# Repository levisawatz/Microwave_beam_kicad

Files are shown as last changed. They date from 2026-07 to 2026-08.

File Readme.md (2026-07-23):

# Steerable Microwave Beam Phased Array
Designer: Levi Sawatzky  
Overview Document: https://levisawatz.github.io/assets/microwave_beam/Project_summary.pdf  
Status: In production

## Project Overview 
This project explores the design and construction of a steerable microwave phased array capable of delivering a tightly focused beam of microwave energy toward a target. The system serves as a science demonstration platform that reveals the power and elegance of microwave circuit design, phased arrays, and high-frequency PCB engineering. The core concept is to electronically steer a beam of RF energy without any moving mechanical parts, using phase control across an array of patch antennas. This beam can then be used to transfer wireless power across a distance, light up LEDs, heat up food like a microwave, or boost WIFI 

This PCB was created using Kicad 10

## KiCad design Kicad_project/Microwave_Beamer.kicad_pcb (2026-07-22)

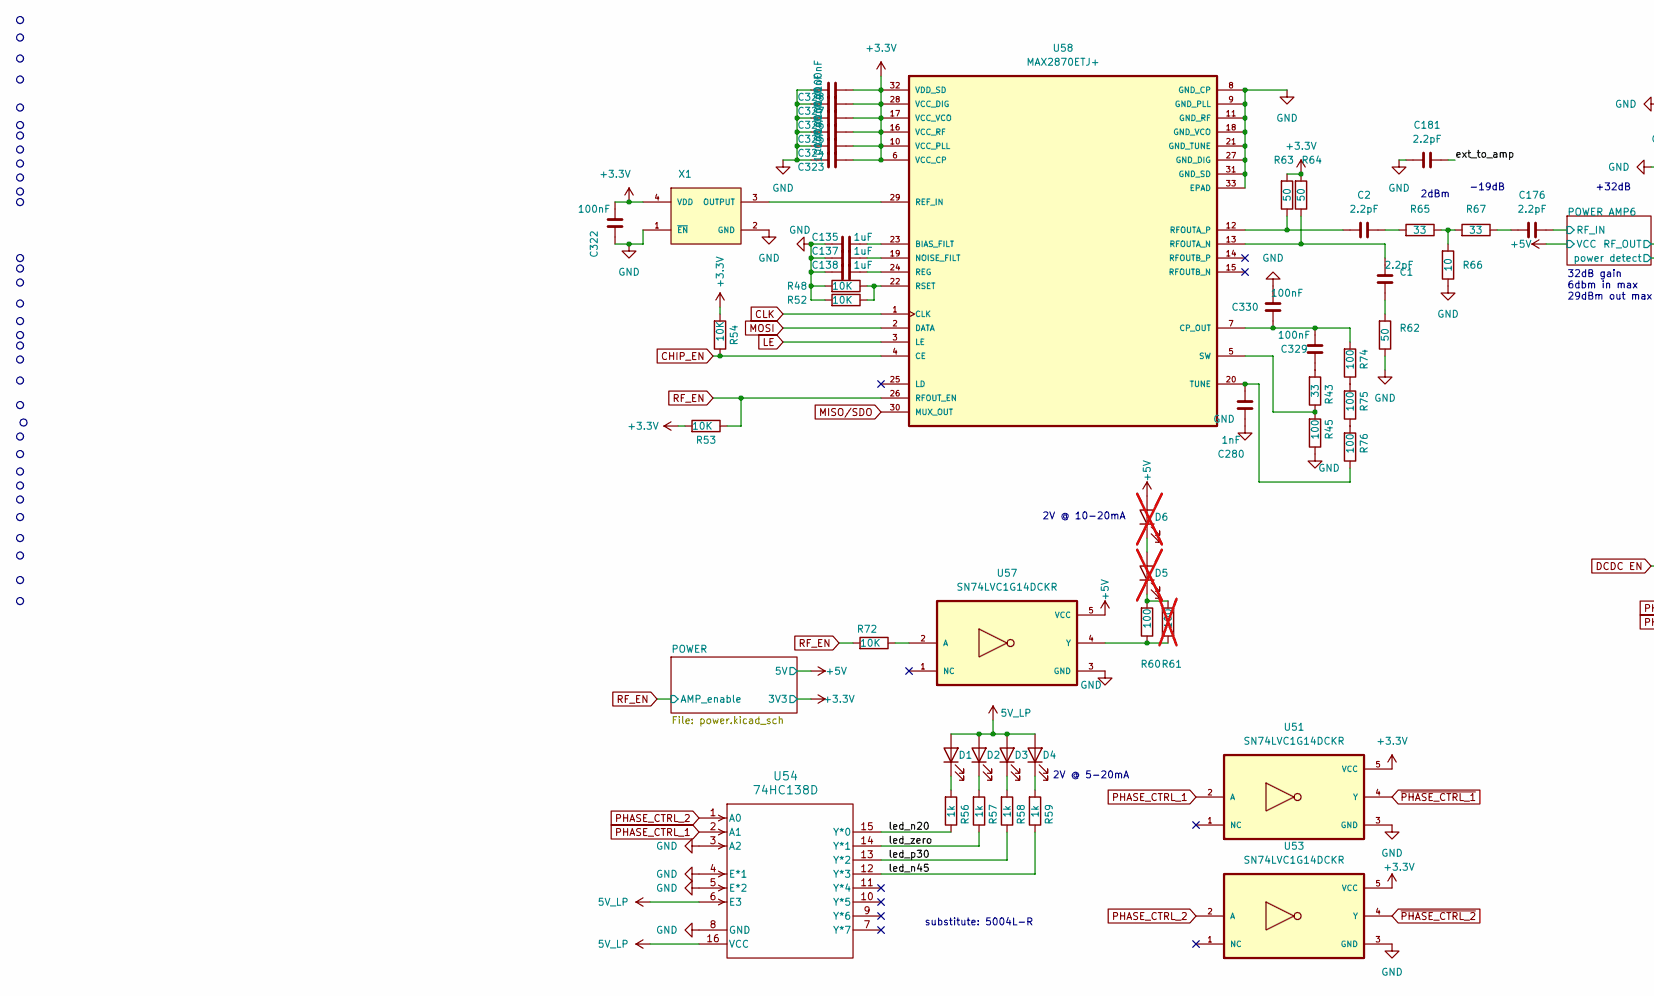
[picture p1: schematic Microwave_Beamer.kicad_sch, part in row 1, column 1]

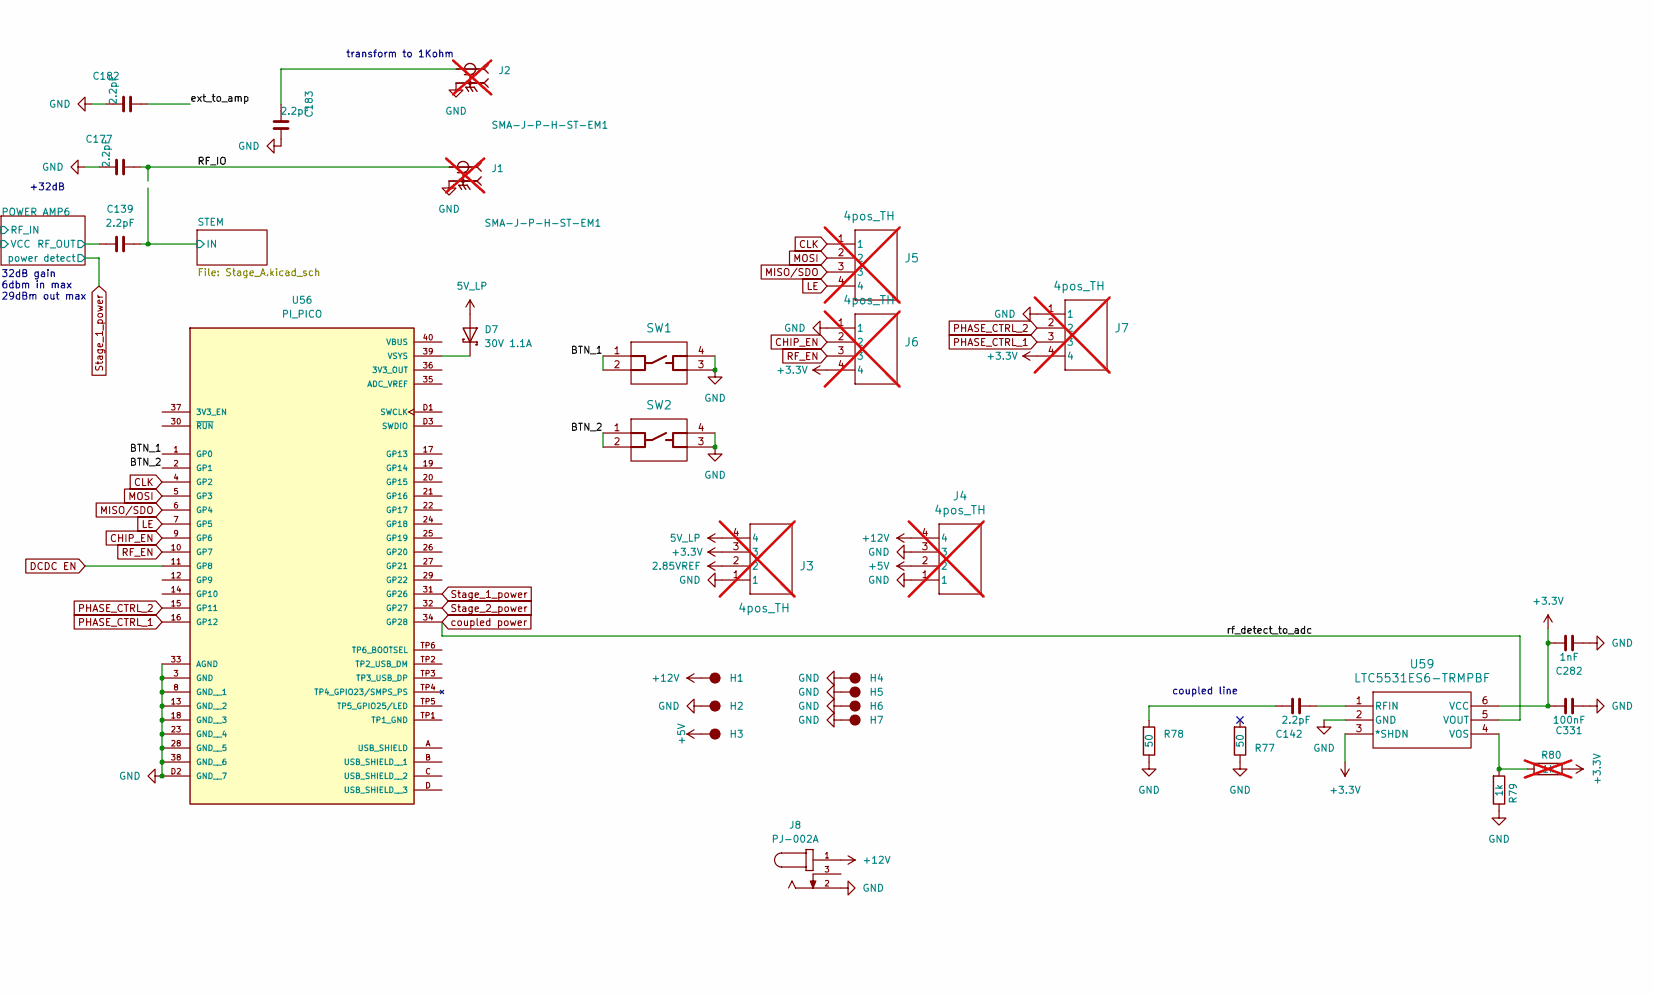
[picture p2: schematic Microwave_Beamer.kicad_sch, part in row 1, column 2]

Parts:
C1, C2, C176: 2.2pF; C_0402_1005Metric; MPN GJM1555C1H2R2WB01D
C135, C137, C138: 1uF; C_0603_1608Metric; MPN GRT188R61H105KE13D
C139, C142, C177, C181, C182, C183: 2.2pF; C_0402_1005Metric_Pad0.74x0.62mm_HandSolder; MPN GJM1555C1H2R2WB01D
C280, C282: 1nF; C_0402_1005Metric; MPN GCM1555C1H102GA16J
C322, C323, C324, C325, C326, C327, C328, C329, C330, C331: 100nF; C_0402_1005Metric; MPN GCM155R71H104KE02J
D1, D2, D3, D4: LTST-C230KGKT; LED_1206_3216Metric; MPN LTST-C230KGKT
D5, D6: LTST-C230KGKT; LED_1206_3216Metric; MPN LTST-C230KRKT; not fitted
D7: 30V 1.1A; CR_03-GS08_VIS; MPN SL03-GS08
H1, H2, H3, H4, H5, H6, H7: Hole; PTH_5mm; MPN DNP
J1, J2: SMA-J-P-H-ST-EM1; SAMTEC_SMA-J-P-H-ST-EM1; PARTREV G; not fitted
J3, J4, J5, J6, J7: 4pos_TH; 4POS-2_54-generic; MPN DNP; not fitted
J8: PJ-002A; CUI_PJ-002A; MPN PJ-002A
R43, R65, R67: 33; R_0402_1005Metric; MPN TNPW040233R0DEED
R45, R60, R74, R75, R76: 100; R_0402_1005Metric; MPN ERA-2AED101X
R48, R52, R53, R54, R72: 10K; R_0603_1608Metric; MPN ERA-3AEB103V
R56, R57, R58, R59, R79: 1k; R_0603_1608Metric; MPN ERA-3AEB102V
R61: 100; R_0402_1005Metric; MPN ERA-2AED101X; not fitted
R62, R63, R64: 50; R_0402_1005Metric; MPN TNPW040249R9BEED
R66: 10; R_0402_1005Metric; MPN TNPW040210R0DEED
R77, R78: 50; R_0402_1005Metric_Pad0.72x0.64mm_HandSolder; MPN TNPW040249R9BEED
R80: 1k; R_0603_1608Metric; MPN ERA-3AEB102V; not fitted
SW1, SW2: PTS526SM15SMTR2 LFS; SON4_PTS526 SM15 SMTR2 LFS_CNK-M; MPN PTS526SM15SMTR2 LFS
U51, U53, U57: SN74LVC1G14DCKR; SOT65P210X110-5N; MPN SN74LVC1G14DCKR
U54: 74HC138D; SOT109-1_NXP; MPN MC74HC138ADR2G
U56: PI_PICO; PI_PICO_SMD; MPN SC0917
U58: MAX2870ETJ+; vco_QFN50P500X500X80-33N; MPN MAX2870ETJ+
U59: LTC5531ES6-TRMPBF; SOT-6_S_LIT-M; MPN LTC5531ES6#TRMPBF
X1: ECS-3225MVQ-1000-CN-TR; OSC_ECS-3225MVQ-1000-CN-TR; MPN ECS-3225MVQ-1000-CN-TR

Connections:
2.85VREF: J3.2; also elsewhere on the board
5V_LP: D1.2 (A), D2.2 (A), D3.2 (A), D4.2 (A), D7.A, J3.4, U54.6 (E3), U54.16 (VCC); also elsewhere on the board
+3.3V: C282.1, C322.2, C323.2, C324.2, C325.2, C326.2, C327.2, C328.2, C331.1, J3.3, J6.4, J7.4, R53.1, R54.1, R63.1, R64.1, R80.2, U51.5 (VCC), U53.5 (VCC), U58.6 (VCC_CP), U58.10 (VCC_PLL), U58.16 (VCC_RF), U58.17 (VCC_VCO), U58.28 (VCC_DIG), U58.32 (VDD_SD), U59.3 (*SHDN), U59.6 (VCC), X1.4 (VDD); also elsewhere on the board
+5V: D6.2 (A), H3.1, J4.2, U57.5 (VCC); also elsewhere on the board
+12V: H1.1, J4.4, J8.1; also elsewhere on the board
/BTN_1: SW1.1, SW1.2, U56.1 (GP0)
/BTN_2: SW2.1, SW2.2, U56.2 (GP1)
/POWER AMP6/RF_IN: C176.2; also elsewhere on the board
/POWER AMP6/RF_OUT: C139.1; also elsewhere on the board
/RF_IO: C177.2, J1.1
/STEM/IN: C139.2; also elsewhere on the board
/ext_to_amp: C181.2, C182.2
/led_n20: R56.2, U54.15 (Y*0)
/led_n45: R59.2, U54.12 (Y*3)
/led_p30: R58.2, U54.13 (Y*2)
/led_zero: R57.2, U54.14 (Y*1)
CHIP_EN: J6.2, R54.2, U56.9 (GP6), U58.4 (CE)
CLK: J5.1, U56.4 (GP2), U58.1 (CLK)
DCDC EN: U56.11 (GP8); also elsewhere on the board
GND: C135.1, C137.1, C138.1, C177.1, C181.1, C182.1, C183.2, C280.2, C282.2, C322.1, C323.1, C324.1, C325.1, C326.1, C327.1, C328.1, C330.1, C331.2, H2.1, H4.1, H5.1, H6.1, H7.1, J1.2_1, J1.2_2, J1.3_1, J1.3_2, J2.2_1, J2.2_2, J2.3_1, J2.3_2, J3.1, J4.1, J4.3, J6.1, J7.1, J8.2, R45.2, R48.1, R52.1, R62.2, R66.2, R77.2, R78.2, R79.2, SW1.3, SW1.4, SW2.3, SW2.4, U51.3 (GND), U53.3 (GND), U54.3 (A2), U54.4 (E*1), U54.5 (E*2), U54.8 (GND), U56.3 (GND), U56.8 (GND__1), U56.13 (GND__2), U56.18 (GND__3), U56.23 (GND__4), U56.28 (GND__5), U56.33 (AGND), U56.38 (GND__6), U56.D2 (GND__7), U57.3 (GND), U58.8 (GND_CP), U58.9 (GND_PLL), U58.11 (GND_RF), U58.18 (GND_VCO), U58.21 (GND_TUNE), U58.27 (GND_DIG), U58.31 (GND_SD), U58.33 (EPAD), U59.2 (GND), X1.1 (~EN), X1.2 (GND); also elsewhere on the board
LE: J5.4, U56.7 (GP5), U58.3 (LE)
MISO/SDO: J5.3, U56.6 (GP4), U58.30 (MUX_OUT)
MOSI: J5.2, U56.5 (GP3), U58.2 (DATA)
unnamed: C1.2, R62.1
unnamed: C2.2, R65.1
unnamed: C142.1, R78.1
unnamed: C176.1, R67.2
unnamed: C183.1, J2.1
unnamed: C329.2, R43.1
unnamed: D1.1 (K), R56.1
unnamed: D2.1 (K), R57.1
unnamed: D3.1 (K), R58.1
unnamed: D4.1 (K), R59.1
unnamed: D5.2 (A), D6.1 (K)
unnamed: D5.1 (K), R60.1, R61.1
unnamed: R65.2, R66.1, R67.1
unnamed: R74.2, R75.1
unnamed: R75.2, R76.1
unnamed: D7.K, U56.39 (VSYS)
unnamed: R72.2, U57.2 (A)
unnamed: R60.2, R61.2, U57.4 (Y)
unnamed: C135.2, U58.23 (BIAS_FILT)
unnamed: C329.1, C330.2, R74.1, U58.7 (CP_OUT)
unnamed: C137.2, U58.19 (NOISE_FILT)
unnamed: U58.29 (REF_IN), X1.3 (OUTPUT)
unnamed: C138.2, U58.24 (REG)
unnamed: C1.1, R64.2, U58.13 (RFOUTA_N)
unnamed: C2.1, R63.2, U58.12 (RFOUTA_P)
unnamed: R48.2, R52.2, U58.22 (RSET)
unnamed: R43.2, R45.1, U58.5 (SW)
unnamed: C280.1, R76.2, U58.20 (TUNE)
unnamed: C142.2, U59.1 (RFIN)
unnamed: R79.1, R80.1, U59.4 (VOS)
PHASE_CTRL_1: J7.3, U51.2 (A), U54.2 (A1), U56.16 (GP12); also elsewhere on the board
PHASE_CTRL_2: J7.2, U53.2 (A), U54.1 (A0), U56.15 (GP11); also elsewhere on the board
RF_EN: J6.3, R53.2, R72.1, U56.10 (GP7), U58.26 (RFOUT_EN); also elsewhere on the board
Stage_1_power: U56.31 (GP26); also elsewhere on the board
Stage_2_power: U56.32 (GP27); also elsewhere on the board
coupled power: U56.34 (GP28), U59.5 (VOUT)
~PHASE_CTRL_1: U51.4 (Y); also elsewhere on the board
~PHASE_CTRL_2: U53.4 (Y); also elsewhere on the board

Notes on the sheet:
coupled line
2V @ 10-20mA
32dB gain 6dbm in max 29dBm out max
2dBm
-19dB
transform to 1Kohm
2V @ 5-20mA
+32dB
substitute: 5004L-R

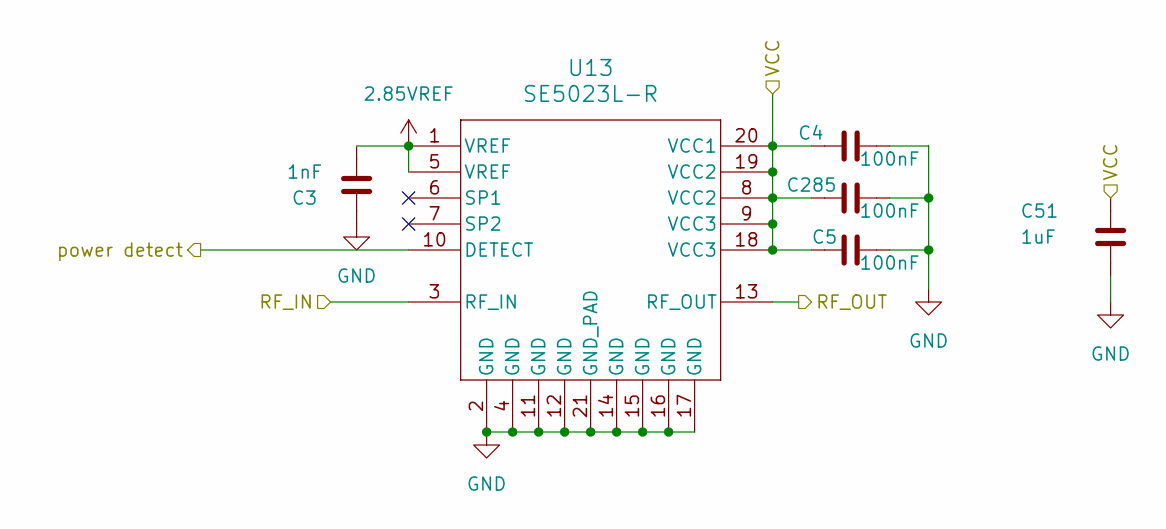
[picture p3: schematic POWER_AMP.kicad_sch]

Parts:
C3: 1nF; C_0402_1005Metric; MPN GCM1555C1H102GA16J
C4, C5, C285: 100nF; C_0402_1005Metric; MPN GCM155R71H104KE02J
C51: 1uF; C_0603_1608Metric; MPN GRT188R61H105KE13D
U13: SE5023L-R; QFN20_4X4_STM; MPN 5004L-R

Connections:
2.85VREF: C3.1, U13.1 (VREF), U13.5 (VREF); also elsewhere on the board
+5V: C4.1, C5.1, C51.1, C285.1, U13.8 (VCC2), U13.9 (VCC3), U13.18 (VCC3), U13.19 (VCC2), U13.20 (VCC1); also elsewhere on the board
/STEM/FAN_A/Antenna_1: U13.13 (RF_OUT)
/STEM/FAN_A/FANFAN A/OUT1: U13.3 (RF_IN); also elsewhere on the board
/STEM/FAN_A/POWER AMP1/power detect: U13.10 (DETECT)
GND: C3.2, C4.2, C5.2, C51.2, C285.2, U13.2 (GND), U13.4 (GND), U13.11 (GND), U13.12 (GND), U13.14 (GND), U13.15 (GND), U13.16 (GND), U13.17 (GND), U13.21 (GND_PAD); also elsewhere on the board

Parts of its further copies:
C6, C7, C8, C9, C25, C26, C27, C28, C29, C30, C39, C40, C41, C42, C43, C44, C46, C47, C48, C49, C50, C61, C75, C89, C103, C117, C131, C145, C159, C173, C187, C201, C215, C229, C243, C257, C286, C287, C288, C289, C290, C291, C292, C293, C294, C295, C296, C297, C298, C299, C300, C301, C302, C303: 100nF; C_0402_1005Metric; MPN GCM155R71H104KE02J
C24, C38, C45, C59, C73, C87, C101, C115, C129, C143, C157, C171, C185, C199, C213, C227, C241, C255: 1nF; C_0402_1005Metric; MPN GCM1555C1H102GA16J
C60, C62, C63, C64, C65, C74, C76, C77, C78, C79, C88, C90, C91, C92, C93, C102, C104, C105: 1uF; C_0603_1608Metric; MPN GRT188R61H105KE13D
U16, U18, U19, U21, U23, U25, U27, U29, U31, U33, U35, U37, U39, U41, U43, U45, U47, U49: SE5023L-R; QFN20_4X4_STM; MPN 5004L-R

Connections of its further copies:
2.85VREF: C24.1, C38.1, C45.1, C59.1, C73.1, C87.1, C101.1, C115.1, C129.1, C143.1, C157.1, C171.1, C185.1, C199.1, C213.1, C227.1, C241.1, C255.1, U16.1 (VREF), U16.5 (VREF), U18.1 (VREF), U18.5 (VREF), U19.1 (VREF), U19.5 (VREF), U21.1 (VREF), U21.5 (VREF), U23.1 (VREF), U23.5 (VREF), U25.1 (VREF), U25.5 (VREF), U27.1 (VREF), U27.5 (VREF), U29.1 (VREF), U29.5 (VREF), U31.1 (VREF), U31.5 (VREF), U33.1 (VREF), U33.5 (VREF), U35.1 (VREF), U35.5 (VREF), U37.1 (VREF), U37.5 (VREF), U39.1 (VREF), U39.5 (VREF), U41.1 (VREF), U41.5 (VREF), U43.1 (VREF), U43.5 (VREF), U45.1 (VREF), U45.5 (VREF), U47.1 (VREF), U47.5 (VREF), U49.1 (VREF), U49.5 (VREF); also elsewhere on the board
+5V: C6.1, C7.1, C8.1, C9.1, C25.1, C26.1, C27.1, C28.1, C29.1, C30.1, C39.1, C40.1, C41.1, C42.1, C43.1, C44.1, C46.1, C47.1, C48.1, C49.1, C50.1, C60.1, C61.1, C62.1, C63.1, C64.1, C65.1, C74.1, C75.1, C76.1, C77.1, C78.1, C79.1, C88.1, C89.1, C90.1, C91.1, C92.1, C93.1, C102.1, C103.1, C104.1, C105.1, C117.1, C131.1, C145.1, C159.1, C173.1, C187.1, C201.1, C215.1, C229.1, C243.1, C257.1, C286.1, C287.1, C288.1, C289.1, C290.1, C291.1, C292.1, C293.1, C294.1, C295.1, C296.1, C297.1, C298.1, C299.1, C300.1, C301.1, C302.1, C303.1, U16.8 (VCC2), U16.9 (VCC3), U16.18 (VCC3), U16.19 (VCC2), U16.20 (VCC1), U18.8 (VCC2), U18.9 (VCC3), U18.18 (VCC3), U18.19 (VCC2), U18.20 (VCC1), U19.8 (VCC2), U19.9 (VCC3), U19.18 (VCC3), U19.19 (VCC2), U19.20 (VCC1), U21.8 (VCC2), U21.9 (VCC3), U21.18 (VCC3), U21.19 (VCC2), U21.20 (VCC1), U23.8 (VCC2), U23.9 (VCC3), U23.18 (VCC3), U23.19 (VCC2), U23.20 (VCC1), U25.8 (VCC2), U25.9 (VCC3), U25.18 (VCC3), U25.19 (VCC2), U25.20 (VCC1), U27.8 (VCC2), U27.9 (VCC3), U27.18 (VCC3), U27.19 (VCC2), U27.20 (VCC1), U29.8 (VCC2), U29.9 (VCC3), U29.18 (VCC3), U29.19 (VCC2), U29.20 (VCC1), U31.8 (VCC2), U31.9 (VCC3), U31.18 (VCC3), U31.19 (VCC2), U31.20 (VCC1), U33.8 (VCC2), U33.9 (VCC3), U33.18 (VCC3), U33.19 (VCC2), U33.20 (VCC1), U35.8 (VCC2), U35.9 (VCC3), U35.18 (VCC3), U35.19 (VCC2), U35.20 (VCC1), U37.8 (VCC2), U37.9 (VCC3), U37.18 (VCC3), U37.19 (VCC2), U37.20 (VCC1), U39.8 (VCC2), U39.9 (VCC3), U39.18 (VCC3), U39.19 (VCC2), U39.20 (VCC1), U41.8 (VCC2), U41.9 (VCC3), U41.18 (VCC3), U41.19 (VCC2), U41.20 (VCC1), U43.8 (VCC2), U43.9 (VCC3), U43.18 (VCC3), U43.19 (VCC2), U43.20 (VCC1), U45.8 (VCC2), U45.9 (VCC3), U45.18 (VCC3), U45.19 (VCC2), U45.20 (VCC1), U47.8 (VCC2), U47.9 (VCC3), U47.18 (VCC3), U47.19 (VCC2), U47.20 (VCC1), U49.8 (VCC2), U49.9 (VCC3), U49.18 (VCC3), U49.19 (VCC2), U49.20 (VCC1); also elsewhere on the board
/POWER AMP6/RF_IN: U49.3 (RF_IN); also elsewhere on the board
/POWER AMP6/RF_OUT: U49.13 (RF_OUT); also elsewhere on the board
/STEM/FAN_A/Antenna_3: U16.13 (RF_OUT)
/STEM/FAN_A/Antenna_5: U18.13 (RF_OUT)
/STEM/FAN_A/FANFAN A/OUT3: U16.3 (RF_IN); also elsewhere on the board
/STEM/FAN_A/FANFAN A/OUT5: U18.3 (RF_IN); also elsewhere on the board
/STEM/FAN_A/POWER AMP3/power detect: U16.10 (DETECT)
/STEM/FAN_A/power_det: U18.10 (DETECT)
/STEM/FAN_B/Antenna_1: U19.13 (RF_OUT)
/STEM/FAN_B/Antenna_3: U21.13 (RF_OUT)
/STEM/FAN_B/Antenna_5: U23.13 (RF_OUT)
/STEM/FAN_B/FANFAN A/OUT1: U19.3 (RF_IN); also elsewhere on the board
/STEM/FAN_B/FANFAN A/OUT3: U21.3 (RF_IN); also elsewhere on the board
/STEM/FAN_B/FANFAN A/OUT5: U23.3 (RF_IN); also elsewhere on the board
/STEM/FAN_B/POWER AMP1/power detect: U19.10 (DETECT)
/STEM/FAN_B/POWER AMP3/power detect: U21.10 (DETECT)
/STEM/FAN_C/Antenna_1: U25.13 (RF_OUT)
/STEM/FAN_C/Antenna_3: U27.13 (RF_OUT)
/STEM/FAN_C/Antenna_5: U29.13 (RF_OUT)
/STEM/FAN_C/FANFAN A/OUT1: U25.3 (RF_IN); also elsewhere on the board
/STEM/FAN_C/FANFAN A/OUT3: U27.3 (RF_IN); also elsewhere on the board
/STEM/FAN_C/FANFAN A/OUT5: U29.3 (RF_IN); also elsewhere on the board
/STEM/FAN_C/POWER AMP1/power detect: U25.10 (DETECT)
/STEM/FAN_C/POWER AMP3/power detect: U27.10 (DETECT)
/STEM/FAN_C/power_det: U29.10 (DETECT)
/STEM/FAN_D/Antenna_1: U31.13 (RF_OUT)
/STEM/FAN_D/Antenna_3: U33.13 (RF_OUT)
/STEM/FAN_D/Antenna_5: U35.13 (RF_OUT)
/STEM/FAN_D/FANFAN A/OUT1: U31.3 (RF_IN); also elsewhere on the board
/STEM/FAN_D/FANFAN A/OUT3: U33.3 (RF_IN); also elsewhere on the board
/STEM/FAN_D/FANFAN A/OUT5: U35.3 (RF_IN); also elsewhere on the board
/STEM/FAN_D/POWER AMP1/power detect: U31.10 (DETECT)
/STEM/FAN_D/POWER AMP3/power detect: U33.10 (DETECT)
/STEM/FAN_D/power_det: U35.10 (DETECT)
/STEM/FAN_E/Antenna_1: U37.13 (RF_OUT)
/STEM/FAN_E/Antenna_3: U39.13 (RF_OUT)
/STEM/FAN_E/Antenna_5: U41.13 (RF_OUT)
/STEM/FAN_E/FANFAN A/OUT1: U37.3 (RF_IN); also elsewhere on the board
/STEM/FAN_E/FANFAN A/OUT3: U39.3 (RF_IN); also elsewhere on the board
/STEM/FAN_E/FANFAN A/OUT5: U41.3 (RF_IN); also elsewhere on the board
/STEM/FAN_E/POWER AMP1/power detect: U37.10 (DETECT)
/STEM/FAN_E/POWER AMP3/power detect: U39.10 (DETECT)
/STEM/FAN_E/power_det: U41.10 (DETECT)
/STEM/FAN_F/Antenna_1: U43.13 (RF_OUT)
/STEM/FAN_F/Antenna_3: U45.13 (RF_OUT)
/STEM/FAN_F/Antenna_5: U47.13 (RF_OUT)
/STEM/FAN_F/FANFAN A/OUT1: U43.3 (RF_IN); also elsewhere on the board
/STEM/FAN_F/FANFAN A/OUT3: U45.3 (RF_IN); also elsewhere on the board
/STEM/FAN_F/FANFAN A/OUT5: U47.3 (RF_IN); also elsewhere on the board
/STEM/FAN_F/POWER AMP1/power detect: U43.10 (DETECT)
/STEM/FAN_F/POWER AMP3/power detect: U45.10 (DETECT)
/STEM/FAN_F/power_det: U47.10 (DETECT)
GND: C6.2, C7.2, C8.2, C9.2, C24.2, C25.2, C26.2, C27.2, C28.2, C29.2, C30.2, C38.2, C39.2, C40.2, C41.2, C42.2, C43.2, C44.2, C45.2, C46.2, C47.2, C48.2, C49.2, C50.2, C59.2, C60.2, C61.2, C62.2, C63.2, C64.2, C65.2, C73.2, C74.2, C75.2, C76.2, C77.2, C78.2, C79.2, C87.2, C88.2, C89.2, C90.2, C91.2, C92.2, C93.2, C101.2, C102.2, C103.2, C104.2, C105.2, C115.2, C117.2, C129.2, C131.2, C143.2, C145.2, C157.2, C159.2, C171.2, C173.2, C185.2, C187.2, C199.2, C201.2, C213.2, C215.2, C227.2, C229.2, C241.2, C243.2, C255.2, C257.2, C286.2, C287.2, C288.2, C289.2, C290.2, C291.2, C292.2, C293.2, C294.2, C295.2, C296.2, C297.2, C298.2, C299.2, C300.2, C301.2, C302.2, C303.2, U16.2 (GND), U16.4 (GND), U16.11 (GND), U16.12 (GND), U16.14 (GND), U16.15 (GND), U16.16 (GND), U16.17 (GND), U16.21 (GND_PAD), U18.2 (GND), U18.4 (GND), U18.11 (GND), U18.12 (GND), U18.14 (GND), U18.15 (GND), U18.16 (GND), U18.17 (GND), U18.21 (GND_PAD), U19.2 (GND), U19.4 (GND), U19.11 (GND), U19.12 (GND), U19.14 (GND), U19.15 (GND), U19.16 (GND), U19.17 (GND), U19.21 (GND_PAD), U21.2 (GND), U21.4 (GND), U21.11 (GND), U21.12 (GND), U21.14 (GND), U21.15 (GND), U21.16 (GND), U21.17 (GND), U21.21 (GND_PAD), U23.2 (GND), U23.4 (GND), U23.11 (GND), U23.12 (GND), U23.14 (GND), U23.15 (GND), U23.16 (GND), U23.17 (GND), U23.21 (GND_PAD), U25.2 (GND), U25.4 (GND), U25.11 (GND), U25.12 (GND), U25.14 (GND), U25.15 (GND), U25.16 (GND), U25.17 (GND), U25.21 (GND_PAD), U27.2 (GND), U27.4 (GND), U27.11 (GND), U27.12 (GND), U27.14 (GND), U27.15 (GND), U27.16 (GND), U27.17 (GND), U27.21 (GND_PAD), U29.2 (GND), U29.4 (GND), U29.11 (GND), U29.12 (GND), U29.14 (GND), U29.15 (GND), U29.16 (GND), U29.17 (GND), U29.21 (GND_PAD), U31.2 (GND), U31.4 (GND), U31.11 (GND), U31.12 (GND), U31.14 (GND), U31.15 (GND), U31.16 (GND), U31.17 (GND), U31.21 (GND_PAD), U33.2 (GND), U33.4 (GND), U33.11 (GND), U33.12 (GND), U33.14 (GND), U33.15 (GND), U33.16 (GND), U33.17 (GND), U33.21 (GND_PAD), U35.2 (GND), U35.4 (GND), U35.11 (GND), U35.12 (GND), U35.14 (GND), U35.15 (GND), U35.16 (GND), U35.17 (GND), U35.21 (GND_PAD), U37.2 (GND), U37.4 (GND), U37.11 (GND), U37.12 (GND), U37.14 (GND), U37.15 (GND), U37.16 (GND), U37.17 (GND), U37.21 (GND_PAD), U39.2 (GND), U39.4 (GND), U39.11 (GND), U39.12 (GND), U39.14 (GND), U39.15 (GND), U39.16 (GND), U39.17 (GND), U39.21 (GND_PAD), U41.2 (GND), U41.4 (GND), U41.11 (GND), U41.12 (GND), U41.14 (GND), U41.15 (GND), U41.16 (GND), U41.17 (GND), U41.21 (GND_PAD), U43.2 (GND), U43.4 (GND), U43.11 (GND), U43.12 (GND), U43.14 (GND), U43.15 (GND), U43.16 (GND), U43.17 (GND), U43.21 (GND_PAD), U45.2 (GND), U45.4 (GND), U45.11 (GND), U45.12 (GND), U45.14 (GND), U45.15 (GND), U45.16 (GND), U45.17 (GND), U45.21 (GND_PAD), U47.2 (GND), U47.4 (GND), U47.11 (GND), U47.12 (GND), U47.14 (GND), U47.15 (GND), U47.16 (GND), U47.17 (GND), U47.21 (GND_PAD), U49.2 (GND), U49.4 (GND), U49.11 (GND), U49.12 (GND), U49.14 (GND), U49.15 (GND), U49.16 (GND), U49.17 (GND), U49.21 (GND_PAD); also elsewhere on the board
Stage_1_power: U49.10 (DETECT); also elsewhere on the board
Stage_2_power: U23.10 (DETECT); also elsewhere on the board

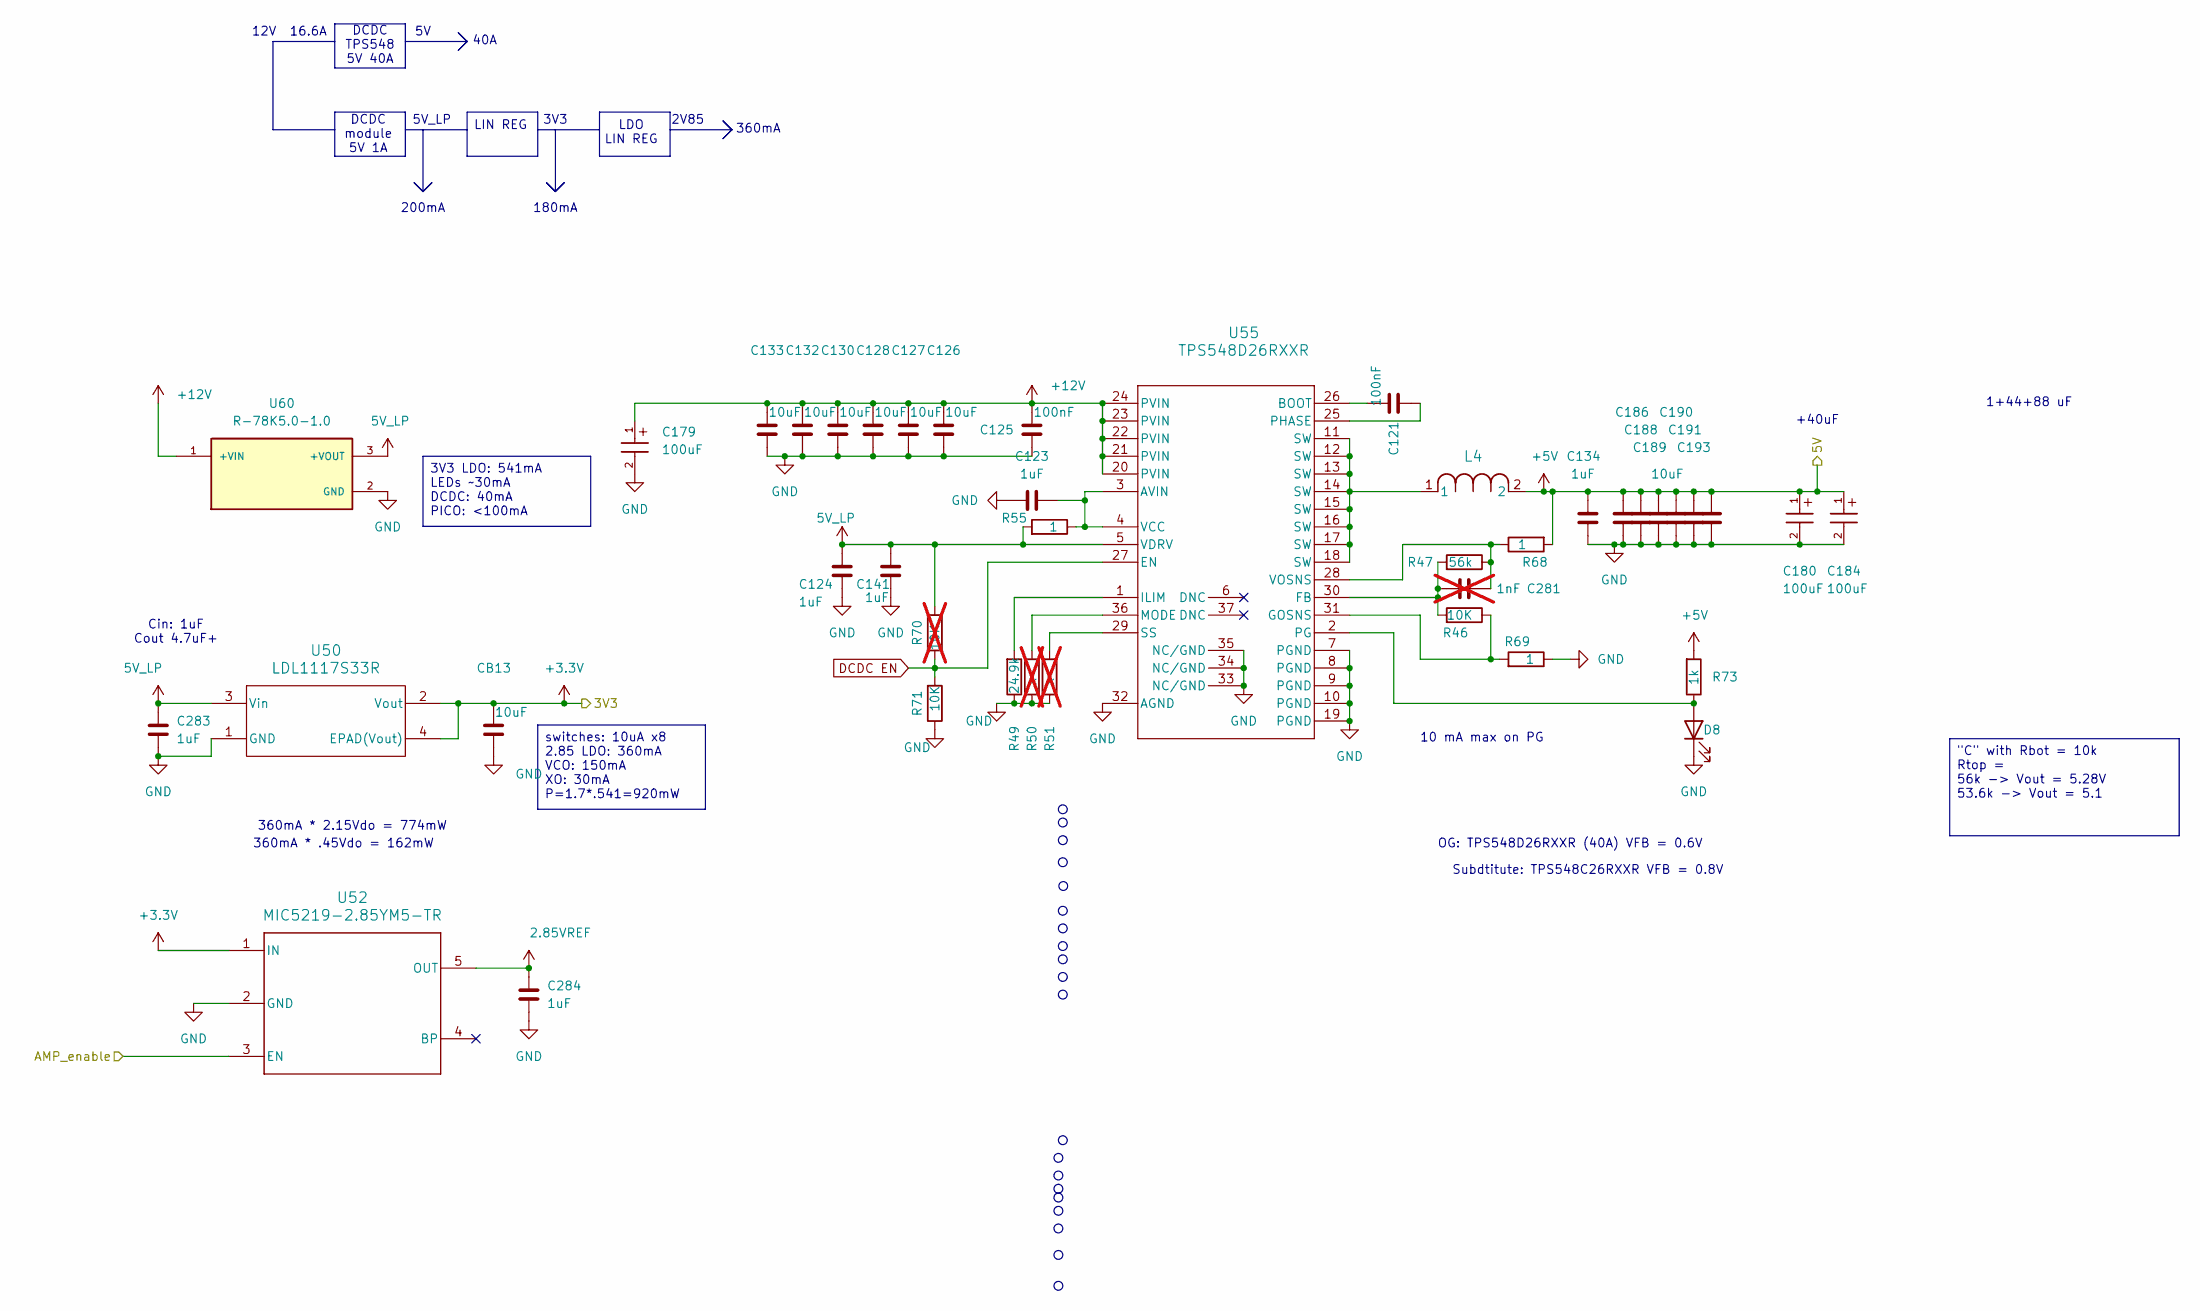
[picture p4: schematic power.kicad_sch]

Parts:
C121, C125: 100nF; C_0402_1005Metric; MPN GCM155R71H104KE02J
C123, C124, C134, C141, C283, C284: 1uF; C_0603_1608Metric; MPN GRT188R61H105KE13D
C126, C127, C128, C130, C132, C133, C186, C188, C189, C190, C191, C193: 10uF; C_1206_3216Metric; MPN GRT31CR6YA106KE01K
C179, C180, C184: 100uF; WCAP-ASLI_6.3X7.7_DXL_; MPN 865080545012
C281: 1nF; C_0402_1005Metric; MPN GCM1555C1H102GA16J; not fitted
CB13: 10uF; C_1206_3216Metric; MPN GRT31CR6YA106KE01K
D8: LTST-C230KGKT; LED_1206_3216Metric; MPN LTST-C230KGKT
L4: IHLP6767GZERR47M11; IND_IHLP-6767GZ_VIS; MPN IHLP6767GZERR47M11
R46, R71: 10K; R_0603_1608Metric; MPN ERA-3AEB103V
R47: 56k; R_0603_1608Metric; MPN ERA-3AEB563V
R49: 24.9k; R_0603_1608Metric; MPN ERA-3AEB2492V
R50, R51: x; R_0603_1608Metric; MPN x; not fitted
R55, R68, R69: 1; R_0603_1608Metric; MPN ERJ-3RQF1R0V
R70: 10K; R_0603_1608Metric; MPN ERA-3AEB103V; not fitted
R73: 1k; R_0603_1608Metric; MPN ERA-3AEB102V
U50: LDL1117S33R; SOT-223_DIO; MPN LDL1117S33R (LDI1117-3.3H)
U52: MIC5219-2.85YM5-TR; SOT23-5; MPN MIC5219-2.85YM5-TR
U55: TPS548D26RXXR; WQFN_C26RXXR_TEX; MPN TPS548D26RXXR
U60: R-78K5.0-1.0; DCDC_R-78K3.3-0.5; MPN R-78K5.0-1.0

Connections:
2.85VREF: C284.1, U52.5 (OUT); also elsewhere on the board
5V_LP: C124.1, C141.1, C283.1, R55.1, R70.2, U50.3 (Vin), U55.5 (VDRV), U60.3 (+VOUT); also elsewhere on the board
+3.3V: CB13.1, U50.2 (Vout), U50.4 (EPAD(Vout)), U52.1 (IN); also elsewhere on the board
+5V: C134.1, C180.1, C184.1, C186.1, C188.1, C189.1, C190.1, C191.1, C193.1, L4.2, R68.1, R73.1; also elsewhere on the board
+12V: C125.1, C126.1, C127.1, C128.1, C130.1, C132.1, C133.1, C179.1, U55.20 (PVIN), U55.21 (PVIN), U55.22 (PVIN), U55.23 (PVIN), U55.24 (PVIN), U60.1 (+VIN); also elsewhere on the board
DCDC EN: R70.1, R71.1, U55.27 (EN); also elsewhere on the board
GND: C123.2, C124.2, C125.2, C126.2, C127.2, C128.2, C130.2, C132.2, C133.2, C134.2, C141.2, C179.2, C180.2, C184.2, C186.2, C188.2, C189.2, C190.2, C191.2, C193.2, C283.2, C284.2, CB13.2, D8.1 (K), R49.2, R50.2, R51.2, R69.2, R71.2, U50.1 (GND), U52.2 (GND), U55.7 (PGND), U55.8 (PGND), U55.9 (PGND), U55.10 (PGND), U55.19 (PGND), U55.32 (AGND), U55.33 (NC/GND), U55.34 (NC/GND), U55.35 (NC/GND), U60.2 (GND); also elsewhere on the board
unnamed: D8.2 (A), R73.2, U55.2 (PG)
unnamed: L4.1, U55.11 (SW), U55.12 (SW), U55.13 (SW), U55.14 (SW), U55.15 (SW), U55.16 (SW), U55.17 (SW), U55.18 (SW)
unnamed: C123.1, R55.2, U55.3 (AVIN), U55.4 (VCC)
unnamed: C121.1, U55.26 (BOOT)
unnamed: C281.1, R46.1, R47.1, U55.30 (FB)
unnamed: R46.2, R69.1, U55.31 (GOSNS)
unnamed: R49.1, U55.1 (ILIM)
unnamed: R50.1, U55.36 (MODE)
unnamed: C121.2, U55.25 (PHASE)
unnamed: R51.1, U55.29 (SS)
unnamed: C281.2, R47.2, R68.2, U55.28 (VOSNS)
RF_EN: U52.3 (EN); also elsewhere on the board

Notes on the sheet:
360mA * .45Vdo = 162mW
2V85
LIN REG
180mA
360mA * 2.15Vdo = 774mW
5V_LP
16.6A
1+44+88 uF
360mA
200mA
Subdtitute: TPS548C26RXXR VFB = 0.8V
OG: TPS548D26RXXR (40A) VFB = 0.6V
DCDC module 5V 1A
Cin: 1uF Cout 4.7uF+
3V3
LDO LIN REG
10 mA max on PG
+40uF
40A
DCDC TPS548 5V 40A
12V
switches: 10uA x8 2.85 LDO: 360mA VCO: 150mA XO: 30mA P=1.7*.541=920mW
"C" with Rbot = 10k Rtop = 56k -> Vout = 5.28V 53.6k -> Vout = 5.1
3V3 LDO: 541mA LEDs ~30mA DCDC: 40mA PICO: <100mA

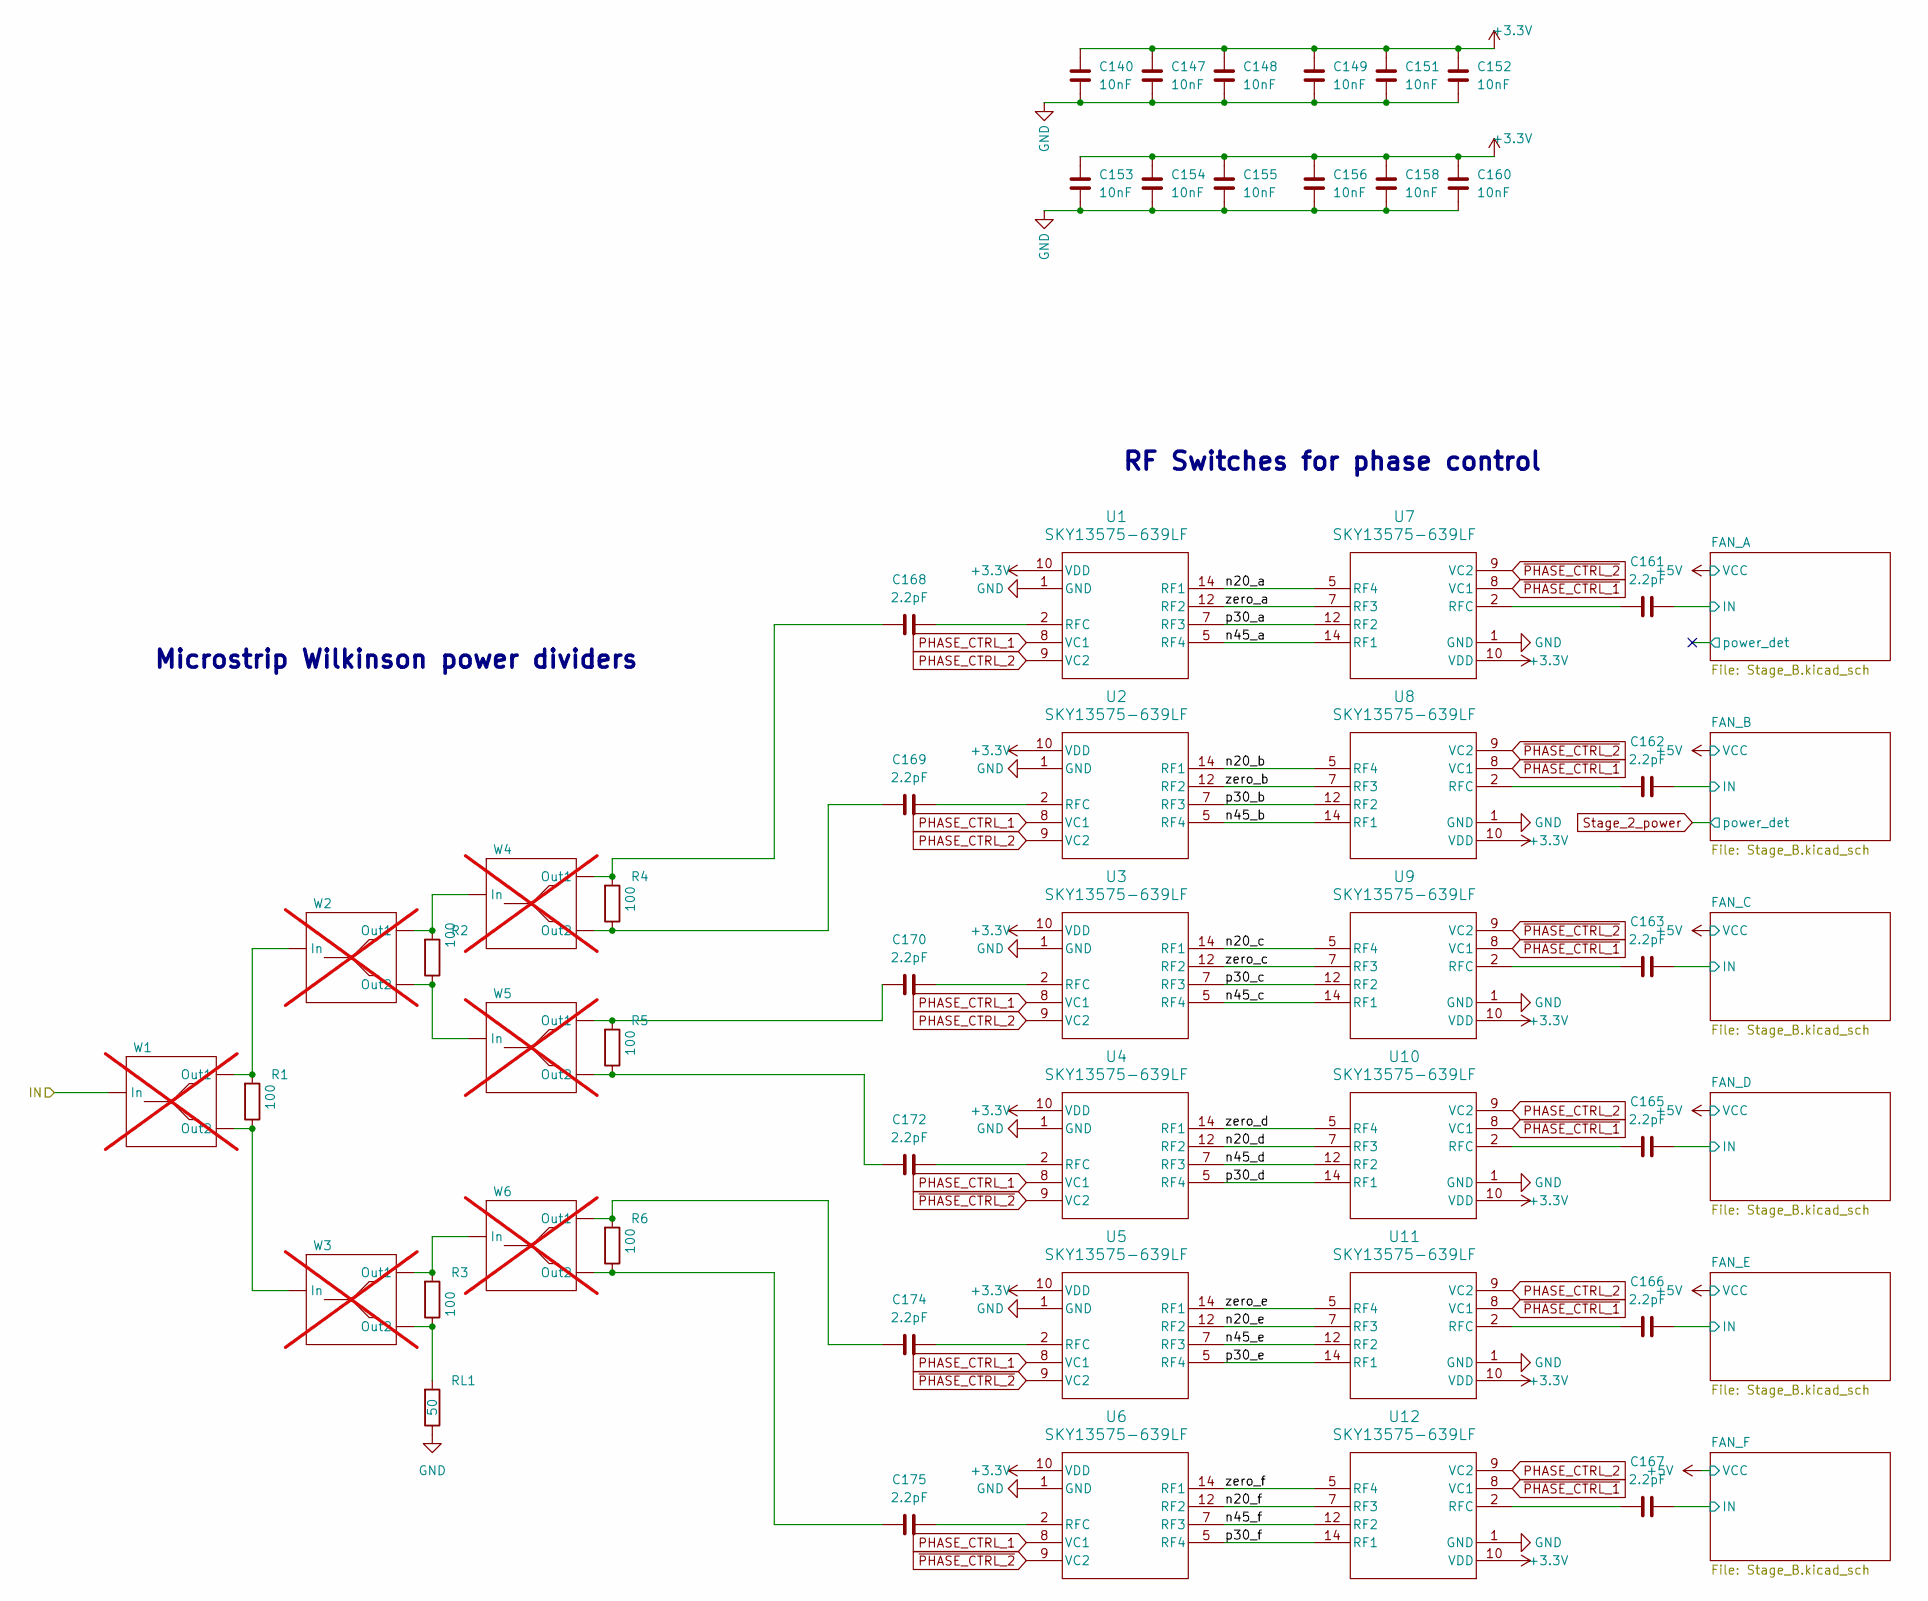
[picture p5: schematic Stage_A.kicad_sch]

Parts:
C140, C147, C148, C149, C151, C152, C153, C154, C155, C156, C158, C160: 10nF; C_0402_1005Metric; MPN GCM155R71H103KA55D
C161, C162, C163, C165, C166, C167, C168, C169, C170, C172, C174, C175: 2.2pF; C_0402_1005Metric; MPN GJM1555C1H2R2WB01D
R1, R2, R3, R4, R5, R6: 100; R_0402_1005Metric; MPN ERA-2AED101X
RL1: 50; R_0402_1005Metric; MPN TNPW040249R9BEED
U1, U2, U3, U4, U5, U6, U7, U8, U9, U10, U11, U12: SKY13575-639LF; SW_SKY13575-639LF; MPN SKY13575-639LF
W1, W2, W3, W4, W5, W6: splitter; 50-70.7 Y; not fitted

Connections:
+3.3V: C140.1, C147.1, C148.1, C149.1, C151.1, C152.1, C153.1, C154.1, C155.1, C156.1, C158.1, C160.1, U1.10 (VDD), U2.10 (VDD), U3.10 (VDD), U4.10 (VDD), U5.10 (VDD), U6.10 (VDD), U7.10 (VDD), U8.10 (VDD), U9.10 (VDD), U10.10 (VDD), U11.10 (VDD), U12.10 (VDD); also elsewhere on the board
/STEM/FAN_A/IN: C161.2; also elsewhere on the board
/STEM/FAN_B/IN: C162.2; also elsewhere on the board
/STEM/FAN_C/IN: C163.2; also elsewhere on the board
/STEM/FAN_D/IN: C165.2; also elsewhere on the board
/STEM/FAN_E/IN: C166.2; also elsewhere on the board
/STEM/FAN_F/IN: C167.2; also elsewhere on the board
/STEM/IN: W1.1 (In); also elsewhere on the board
/STEM/n20_a: U1.14 (RF1), U7.5 (RF4)
/STEM/n20_b: U2.14 (RF1), U8.5 (RF4)
/STEM/n20_c: U3.14 (RF1), U9.5 (RF4)
/STEM/n20_d: U4.12 (RF2), U10.7 (RF3)
/STEM/n20_e: U5.12 (RF2), U11.7 (RF3)
/STEM/n20_f: U6.12 (RF2), U12.7 (RF3)
/STEM/n45_a: U1.5 (RF4), U7.14 (RF1)
/STEM/n45_b: U2.5 (RF4), U8.14 (RF1)
/STEM/n45_c: U3.5 (RF4), U9.14 (RF1)
/STEM/n45_d: U4.7 (RF3), U10.12 (RF2)
/STEM/n45_e: U5.7 (RF3), U11.12 (RF2)
/STEM/n45_f: U6.7 (RF3), U12.12 (RF2)
/STEM/p30_a: U1.7 (RF3), U7.12 (RF2)
/STEM/p30_b: U2.7 (RF3), U8.12 (RF2)
/STEM/p30_c: U3.7 (RF3), U9.12 (RF2)
/STEM/p30_d: U4.5 (RF4), U10.14 (RF1)
/STEM/p30_e: U5.5 (RF4), U11.14 (RF1)
/STEM/p30_f: U6.5 (RF4), U12.14 (RF1)
/STEM/zero_a: U1.12 (RF2), U7.7 (RF3)
/STEM/zero_b: U2.12 (RF2), U8.7 (RF3)
/STEM/zero_c: U3.12 (RF2), U9.7 (RF3)
/STEM/zero_d: U4.14 (RF1), U10.5 (RF4)
/STEM/zero_e: U5.14 (RF1), U11.5 (RF4)
/STEM/zero_f: U6.14 (RF1), U12.5 (RF4)
GND: C140.2, C147.2, C148.2, C149.2, C151.2, C152.2, C153.2, C154.2, C155.2, C156.2, C158.2, C160.2, RL1.2, U1.1 (GND), U1.3 (GND), U1.4 (GND), U1.6 (GND), U1.11 (GND), U1.13 (GND), U1.15 (EPAD), U2.1 (GND), U2.3 (GND), U2.4 (GND), U2.6 (GND), U2.11 (GND), U2.13 (GND), U2.15 (EPAD), U3.1 (GND), U3.3 (GND), U3.4 (GND), U3.6 (GND), U3.11 (GND), U3.13 (GND), U3.15 (EPAD), U4.1 (GND), U4.3 (GND), U4.4 (GND), U4.6 (GND), U4.11 (GND), U4.13 (GND), U4.15 (EPAD), U5.1 (GND), U5.3 (GND), U5.4 (GND), U5.6 (GND), U5.11 (GND), U5.13 (GND), U5.15 (EPAD), U6.1 (GND), U6.3 (GND), U6.4 (GND), U6.6 (GND), U6.11 (GND), U6.13 (GND), U6.15 (EPAD), U7.1 (GND), U7.3 (GND), U7.4 (GND), U7.6 (GND), U7.11 (GND), U7.13 (GND), U7.15 (EPAD), U8.1 (GND), U8.3 (GND), U8.4 (GND), U8.6 (GND), U8.11 (GND), U8.13 (GND), U8.15 (EPAD), U9.1 (GND), U9.3 (GND), U9.4 (GND), U9.6 (GND), U9.11 (GND), U9.13 (GND), U9.15 (EPAD), U10.1 (GND), U10.3 (GND), U10.4 (GND), U10.6 (GND), U10.11 (GND), U10.13 (GND), U10.15 (EPAD), U11.1 (GND), U11.3 (GND), U11.4 (GND), U11.6 (GND), U11.11 (GND), U11.13 (GND), U11.15 (EPAD), U12.1 (GND), U12.3 (GND), U12.4 (GND), U12.6 (GND), U12.11 (GND), U12.13 (GND), U12.15 (EPAD); also elsewhere on the board
unnamed: C168.2, U1.2 (RFC)
unnamed: C169.2, U2.2 (RFC)
unnamed: C170.2, U3.2 (RFC)
unnamed: C172.2, U4.2 (RFC)
unnamed: C174.2, U5.2 (RFC)
unnamed: C175.2, U6.2 (RFC)
unnamed: C161.1, U7.2 (RFC)
unnamed: C162.1, U8.2 (RFC)
unnamed: C163.1, U9.2 (RFC)
unnamed: C165.1, U10.2 (RFC)
unnamed: C166.1, U11.2 (RFC)
unnamed: C167.1, U12.2 (RFC)
unnamed: R1.1, W1.2 (Out1), W2.1 (In)
unnamed: R1.2, W1.3 (Out2), W3.1 (In)
unnamed: R2.1, W2.2 (Out1), W4.1 (In)
unnamed: R2.2, W2.3 (Out2), W5.1 (In)
unnamed: R3.1, W3.2 (Out1), W6.1 (In)
unnamed: R3.2, RL1.1, W3.3 (Out2)
unnamed: C168.1, R4.1, W4.2 (Out1)
unnamed: C169.1, R4.2, W4.3 (Out2)
unnamed: C170.1, R5.1, W5.2 (Out1)
unnamed: C172.1, R5.2, W5.3 (Out2)
unnamed: C174.1, R6.1, W6.2 (Out1)
unnamed: C175.1, R6.2, W6.3 (Out2)
PHASE_CTRL_1: U1.8 (VC1), U2.8 (VC1), U3.8 (VC1), U4.8 (VC1), U5.8 (VC1), U6.8 (VC1); also elsewhere on the board
PHASE_CTRL_2: U1.9 (VC2), U2.9 (VC2), U3.9 (VC2), U10.9 (VC2), U11.9 (VC2), U12.9 (VC2); also elsewhere on the board
~PHASE_CTRL_1: U7.8 (VC1), U8.8 (VC1), U9.8 (VC1), U10.8 (VC1), U11.8 (VC1), U12.8 (VC1); also elsewhere on the board
~PHASE_CTRL_2: U4.9 (VC2), U5.9 (VC2), U6.9 (VC2), U7.9 (VC2), U8.9 (VC2), U9.9 (VC2); also elsewhere on the board

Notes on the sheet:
RF Switches for phase control
Microstrip Wilkinson power dividers

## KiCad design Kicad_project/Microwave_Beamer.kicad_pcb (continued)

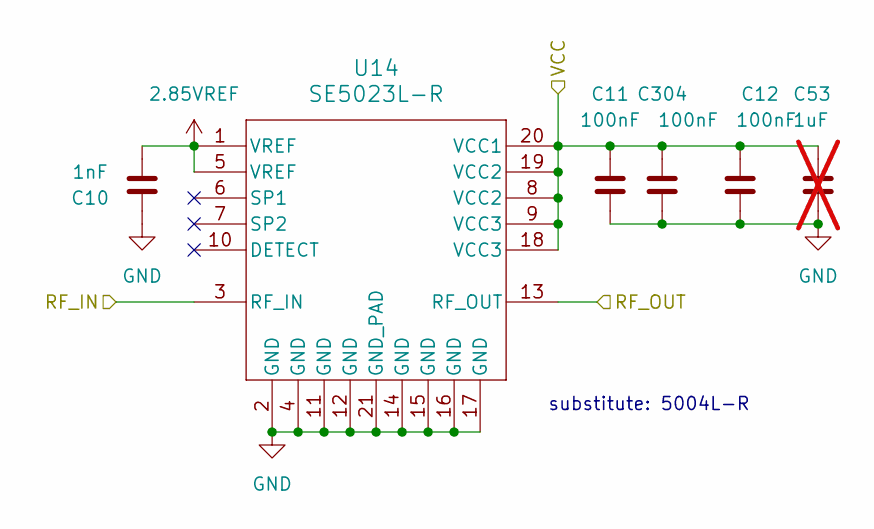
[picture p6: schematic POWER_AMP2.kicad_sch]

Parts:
C10: 1nF; C_0402_1005Metric; MPN GCM1555C1H102GA16J
C11, C12, C304: 100nF; C_0402_1005Metric; MPN GCM155R71H104KE02J
C53: 1uF; C_0603_1608Metric; MPN GRT188R61H105KE13D; not fitted
U14: SE5023L-R; QFN20_4X4_STM; MPN 5004L-R

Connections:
2.85VREF: C10.1, U14.1 (VREF), U14.5 (VREF); also elsewhere on the board
+5V: C11.1, C12.1, C53.1, C304.1, U14.8 (VCC2), U14.9 (VCC3), U14.18 (VCC3), U14.19 (VCC2), U14.20 (VCC1); also elsewhere on the board
/STEM/FAN_A/Antenna_2: U14.13 (RF_OUT)
/STEM/FAN_A/FANFAN A/OUT2: U14.3 (RF_IN); also elsewhere on the board
GND: C10.2, C11.2, C12.2, C53.2, C304.2, U14.2 (GND), U14.4 (GND), U14.11 (GND), U14.12 (GND), U14.14 (GND), U14.15 (GND), U14.16 (GND), U14.17 (GND), U14.21 (GND_PAD); also elsewhere on the board

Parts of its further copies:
C13, C14, C15, C16, C18, C19, C20, C21, C22, C23, C32, C33, C34, C35, C36, C37, C70, C71, C81, C82, C84, C85, C95, C96, C98, C99, C106, C107, C110, C111, C113, C114, C118, C119, C305, C306, C307, C308, C309, C310, C311, C312, C313, C314, C315, C316, C317, C318, C319, C320, C321: 100nF; C_0402_1005Metric; MPN GCM155R71H104KE02J
C17, C31, C52, C66, C80, C94, C108, C122, C136, C150, C164, C178, C192, C206, C220, C234, C248: 1nF; C_0402_1005Metric; MPN GCM1555C1H102GA16J
C54, C55, C56, C57, C58, C67, C68, C69, C72, C83, C86, C97, C100, C109, C112, C116, C120: 1uF; C_0603_1608Metric; MPN GRT188R61H105KE13D; not fitted
U15, U17, U20, U22, U24, U26, U28, U30, U32, U34, U36, U38, U40, U42, U44, U46, U48: SE5023L-R; QFN20_4X4_STM; MPN 5004L-R

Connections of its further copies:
2.85VREF: C17.1, C31.1, C52.1, C66.1, C80.1, C94.1, C108.1, C122.1, C136.1, C150.1, C164.1, C178.1, C192.1, C206.1, C220.1, C234.1, C248.1, U15.1 (VREF), U15.5 (VREF), U17.1 (VREF), U17.5 (VREF), U20.1 (VREF), U20.5 (VREF), U22.1 (VREF), U22.5 (VREF), U24.1 (VREF), U24.5 (VREF), U26.1 (VREF), U26.5 (VREF), U28.1 (VREF), U28.5 (VREF), U30.1 (VREF), U30.5 (VREF), U32.1 (VREF), U32.5 (VREF), U34.1 (VREF), U34.5 (VREF), U36.1 (VREF), U36.5 (VREF), U38.1 (VREF), U38.5 (VREF), U40.1 (VREF), U40.5 (VREF), U42.1 (VREF), U42.5 (VREF), U44.1 (VREF), U44.5 (VREF), U46.1 (VREF), U46.5 (VREF), U48.1 (VREF), U48.5 (VREF); also elsewhere on the board
+5V: C13.1, C14.1, C15.1, C16.1, C18.1, C19.1, C20.1, C21.1, C22.1, C23.1, C32.1, C33.1, C34.1, C35.1, C36.1, C37.1, C54.1, C55.1, C56.1, C57.1, C58.1, C67.1, C68.1, C69.1, C70.1, C71.1, C72.1, C81.1, C82.1, C83.1, C84.1, C85.1, C86.1, C95.1, C96.1, C97.1, C98.1, C99.1, C100.1, C106.1, C107.1, C109.1, C110.1, C111.1, C112.1, C113.1, C114.1, C116.1, C118.1, C119.1, C120.1, C305.1, C306.1, C307.1, C308.1, C309.1, C310.1, C311.1, C312.1, C313.1, C314.1, C315.1, C316.1, C317.1, C318.1, C319.1, C320.1, C321.1, U15.8 (VCC2), U15.9 (VCC3), U15.18 (VCC3), U15.19 (VCC2), U15.20 (VCC1), U17.8 (VCC2), U17.9 (VCC3), U17.18 (VCC3), U17.19 (VCC2), U17.20 (VCC1), U20.8 (VCC2), U20.9 (VCC3), U20.18 (VCC3), U20.19 (VCC2), U20.20 (VCC1), U22.8 (VCC2), U22.9 (VCC3), U22.18 (VCC3), U22.19 (VCC2), U22.20 (VCC1), U24.8 (VCC2), U24.9 (VCC3), U24.18 (VCC3), U24.19 (VCC2), U24.20 (VCC1), U26.8 (VCC2), U26.9 (VCC3), U26.18 (VCC3), U26.19 (VCC2), U26.20 (VCC1), U28.8 (VCC2), U28.9 (VCC3), U28.18 (VCC3), U28.19 (VCC2), U28.20 (VCC1), U30.8 (VCC2), U30.9 (VCC3), U30.18 (VCC3), U30.19 (VCC2), U30.20 (VCC1), U32.8 (VCC2), U32.9 (VCC3), U32.18 (VCC3), U32.19 (VCC2), U32.20 (VCC1), U34.8 (VCC2), U34.9 (VCC3), U34.18 (VCC3), U34.19 (VCC2), U34.20 (VCC1), U36.8 (VCC2), U36.9 (VCC3), U36.18 (VCC3), U36.19 (VCC2), U36.20 (VCC1), U38.8 (VCC2), U38.9 (VCC3), U38.18 (VCC3), U38.19 (VCC2), U38.20 (VCC1), U40.8 (VCC2), U40.9 (VCC3), U40.18 (VCC3), U40.19 (VCC2), U40.20 (VCC1), U42.8 (VCC2), U42.9 (VCC3), U42.18 (VCC3), U42.19 (VCC2), U42.20 (VCC1), U44.8 (VCC2), U44.9 (VCC3), U44.18 (VCC3), U44.19 (VCC2), U44.20 (VCC1), U46.8 (VCC2), U46.9 (VCC3), U46.18 (VCC3), U46.19 (VCC2), U46.20 (VCC1), U48.8 (VCC2), U48.9 (VCC3), U48.18 (VCC3), U48.19 (VCC2), U48.20 (VCC1); also elsewhere on the board
/STEM/FAN_A/Antenna_4: U15.13 (RF_OUT)
/STEM/FAN_A/Antenna_6: U17.13 (RF_OUT)
/STEM/FAN_A/FANFAN A/OUT4: U15.3 (RF_IN); also elsewhere on the board
/STEM/FAN_A/FANFAN A/OUT6: U17.3 (RF_IN); also elsewhere on the board
/STEM/FAN_B/Antenna_2: U20.13 (RF_OUT)
/STEM/FAN_B/Antenna_4: U24.13 (RF_OUT)
/STEM/FAN_B/Antenna_6: U22.13 (RF_OUT)
/STEM/FAN_B/FANFAN A/OUT2: U20.3 (RF_IN); also elsewhere on the board
/STEM/FAN_B/FANFAN A/OUT4: U24.3 (RF_IN); also elsewhere on the board
/STEM/FAN_B/FANFAN A/OUT6: U22.3 (RF_IN); also elsewhere on the board
/STEM/FAN_C/Antenna_2: U26.13 (RF_OUT)
/STEM/FAN_C/Antenna_4: U30.13 (RF_OUT)
/STEM/FAN_C/Antenna_6: U28.13 (RF_OUT)
/STEM/FAN_C/FANFAN A/OUT2: U26.3 (RF_IN); also elsewhere on the board
/STEM/FAN_C/FANFAN A/OUT4: U30.3 (RF_IN); also elsewhere on the board
/STEM/FAN_C/FANFAN A/OUT6: U28.3 (RF_IN); also elsewhere on the board
/STEM/FAN_D/Antenna_2: U32.13 (RF_OUT)
/STEM/FAN_D/Antenna_4: U36.13 (RF_OUT)
/STEM/FAN_D/Antenna_6: U34.13 (RF_OUT)
/STEM/FAN_D/FANFAN A/OUT2: U32.3 (RF_IN); also elsewhere on the board
/STEM/FAN_D/FANFAN A/OUT4: U36.3 (RF_IN); also elsewhere on the board
/STEM/FAN_D/FANFAN A/OUT6: U34.3 (RF_IN); also elsewhere on the board
/STEM/FAN_E/Antenna_2: U38.13 (RF_OUT)
/STEM/FAN_E/Antenna_4: U42.13 (RF_OUT)
/STEM/FAN_E/Antenna_6: U40.13 (RF_OUT)
/STEM/FAN_E/FANFAN A/OUT2: U38.3 (RF_IN); also elsewhere on the board
/STEM/FAN_E/FANFAN A/OUT4: U42.3 (RF_IN); also elsewhere on the board
/STEM/FAN_E/FANFAN A/OUT6: U40.3 (RF_IN); also elsewhere on the board
/STEM/FAN_F/Antenna_2: U44.13 (RF_OUT)
/STEM/FAN_F/Antenna_4: U48.13 (RF_OUT)
/STEM/FAN_F/Antenna_6: U46.13 (RF_OUT)
/STEM/FAN_F/FANFAN A/OUT2: U44.3 (RF_IN); also elsewhere on the board
/STEM/FAN_F/FANFAN A/OUT4: U48.3 (RF_IN); also elsewhere on the board
/STEM/FAN_F/FANFAN A/OUT6: U46.3 (RF_IN); also elsewhere on the board
GND: C13.2, C14.2, C15.2, C16.2, C17.2, C18.2, C19.2, C20.2, C21.2, C22.2, C23.2, C31.2, C32.2, C33.2, C34.2, C35.2, C36.2, C37.2, C52.2, C54.2, C55.2, C56.2, C57.2, C58.2, C66.2, C67.2, C68.2, C69.2, C70.2, C71.2, C72.2, C80.2, C81.2, C82.2, C83.2, C84.2, C85.2, C86.2, C94.2, C95.2, C96.2, C97.2, C98.2, C99.2, C100.2, C106.2, C107.2, C108.2, C109.2, C110.2, C111.2, C112.2, C113.2, C114.2, C116.2, C118.2, C119.2, C120.2, C122.2, C136.2, C150.2, C164.2, C178.2, C192.2, C206.2, C220.2, C234.2, C248.2, C305.2, C306.2, C307.2, C308.2, C309.2, C310.2, C311.2, C312.2, C313.2, C314.2, C315.2, C316.2, C317.2, C318.2, C319.2, C320.2, C321.2, U15.2 (GND), U15.4 (GND), U15.11 (GND), U15.12 (GND), U15.14 (GND), U15.15 (GND), U15.16 (GND), U15.17 (GND), U15.21 (GND_PAD), U17.2 (GND), U17.4 (GND), U17.11 (GND), U17.12 (GND), U17.14 (GND), U17.15 (GND), U17.16 (GND), U17.17 (GND), U17.21 (GND_PAD), U20.2 (GND), U20.4 (GND), U20.11 (GND), U20.12 (GND), U20.14 (GND), U20.15 (GND), U20.16 (GND), U20.17 (GND), U20.21 (GND_PAD), U22.2 (GND), U22.4 (GND), U22.11 (GND), U22.12 (GND), U22.14 (GND), U22.15 (GND), U22.16 (GND), U22.17 (GND), U22.21 (GND_PAD), U24.2 (GND), U24.4 (GND), U24.11 (GND), U24.12 (GND), U24.14 (GND), U24.15 (GND), U24.16 (GND), U24.17 (GND), U24.21 (GND_PAD), U26.2 (GND), U26.4 (GND), U26.11 (GND), U26.12 (GND), U26.14 (GND), U26.15 (GND), U26.16 (GND), U26.17 (GND), U26.21 (GND_PAD), U28.2 (GND), U28.4 (GND), U28.11 (GND), U28.12 (GND), U28.14 (GND), U28.15 (GND), U28.16 (GND), U28.17 (GND), U28.21 (GND_PAD), U30.2 (GND), U30.4 (GND), U30.11 (GND), U30.12 (GND), U30.14 (GND), U30.15 (GND), U30.16 (GND), U30.17 (GND), U30.21 (GND_PAD), U32.2 (GND), U32.4 (GND), U32.11 (GND), U32.12 (GND), U32.14 (GND), U32.15 (GND), U32.16 (GND), U32.17 (GND), U32.21 (GND_PAD), U34.2 (GND), U34.4 (GND), U34.11 (GND), U34.12 (GND), U34.14 (GND), U34.15 (GND), U34.16 (GND), U34.17 (GND), U34.21 (GND_PAD), U36.2 (GND), U36.4 (GND), U36.11 (GND), U36.12 (GND), U36.14 (GND), U36.15 (GND), U36.16 (GND), U36.17 (GND), U36.21 (GND_PAD), U38.2 (GND), U38.4 (GND), U38.11 (GND), U38.12 (GND), U38.14 (GND), U38.15 (GND), U38.16 (GND), U38.17 (GND), U38.21 (GND_PAD), U40.2 (GND), U40.4 (GND), U40.11 (GND), U40.12 (GND), U40.14 (GND), U40.15 (GND), U40.16 (GND), U40.17 (GND), U40.21 (GND_PAD), U42.2 (GND), U42.4 (GND), U42.11 (GND), U42.12 (GND), U42.14 (GND), U42.15 (GND), U42.16 (GND), U42.17 (GND), U42.21 (GND_PAD), U44.2 (GND), U44.4 (GND), U44.11 (GND), U44.12 (GND), U44.14 (GND), U44.15 (GND), U44.16 (GND), U44.17 (GND), U44.21 (GND_PAD), U46.2 (GND), U46.4 (GND), U46.11 (GND), U46.12 (GND), U46.14 (GND), U46.15 (GND), U46.16 (GND), U46.17 (GND), U46.21 (GND_PAD), U48.2 (GND), U48.4 (GND), U48.11 (GND), U48.12 (GND), U48.14 (GND), U48.15 (GND), U48.16 (GND), U48.17 (GND), U48.21 (GND_PAD); also elsewhere on the board

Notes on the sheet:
substitute: 5004L-R

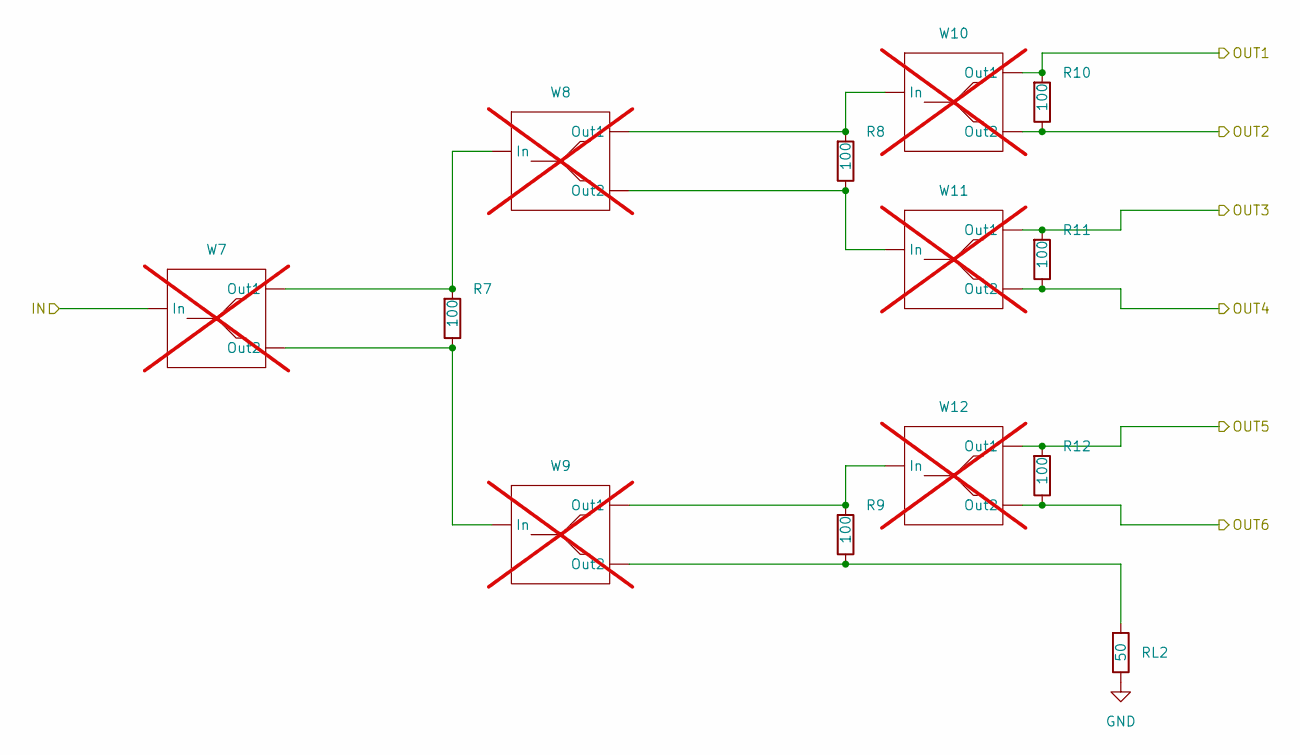
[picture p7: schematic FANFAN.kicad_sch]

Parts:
R7, R8, R9, R10, R11, R12: 100; R_0402_1005Metric; MPN ERA-2AED101X
RL2: 50; R_0402_1005Metric; MPN TNPW040249R9BEED
W7, W8, W9, W10, W11, W12: splitter; 50-70.7 Y; not fitted

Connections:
/STEM/FAN_A/FANFAN A/OUT1: R10.1, W10.2 (Out1); also elsewhere on the board
/STEM/FAN_A/FANFAN A/OUT2: R10.2, W10.3 (Out2); also elsewhere on the board
/STEM/FAN_A/FANFAN A/OUT3: R11.1, W11.2 (Out1); also elsewhere on the board
/STEM/FAN_A/FANFAN A/OUT4: R11.2, W11.3 (Out2); also elsewhere on the board
/STEM/FAN_A/FANFAN A/OUT5: R12.1, W12.2 (Out1); also elsewhere on the board
/STEM/FAN_A/FANFAN A/OUT6: R12.2, W12.3 (Out2); also elsewhere on the board
/STEM/FAN_A/IN: W7.1 (In); also elsewhere on the board
GND: RL2.2; also elsewhere on the board
unnamed: R7.1, W7.2 (Out1), W8.1 (In)
unnamed: R7.2, W7.3 (Out2), W9.1 (In)
unnamed: R9.2, RL2.1, W9.3 (Out2)
unnamed: R8.1, W8.2 (Out1), W10.1 (In)
unnamed: R8.2, W8.3 (Out2), W11.1 (In)
unnamed: R9.1, W9.2 (Out1), W12.1 (In)

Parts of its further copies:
R13, R14, R15, R16, R17, R18, R19, R20, R21, R22, R23, R24, R25, R26, R27, R28, R29, R30, R31, R32, R33, R34, R35, R36, R37, R38, R39, R40, R41, R42: 100; R_0402_1005Metric; MPN ERA-2AED101X
RL3, RL4, RL5, RL6, RL7: 50; R_0402_1005Metric; MPN TNPW040249R9BEED
W13, W14, W15, W16, W17, W18, W19, W20, W21, W22, W23, W24, W25, W26, W27, W28, W29, W30, W31, W32, W33, W34, W35, W36, W37, W38, W39, W40, W41, W42: splitter; 50-70.7 Y; not fitted

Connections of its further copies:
/STEM/FAN_B/FANFAN A/OUT1: R16.1, W16.2 (Out1); also elsewhere on the board
/STEM/FAN_B/FANFAN A/OUT2: R16.2, W16.3 (Out2); also elsewhere on the board
/STEM/FAN_B/FANFAN A/OUT3: R17.1, W17.2 (Out1); also elsewhere on the board
/STEM/FAN_B/FANFAN A/OUT4: R17.2, W17.3 (Out2); also elsewhere on the board
/STEM/FAN_B/FANFAN A/OUT5: R18.1, W18.2 (Out1); also elsewhere on the board
/STEM/FAN_B/FANFAN A/OUT6: R18.2, W18.3 (Out2); also elsewhere on the board
/STEM/FAN_B/IN: W13.1 (In); also elsewhere on the board
/STEM/FAN_C/FANFAN A/OUT1: R22.1, W22.2 (Out1); also elsewhere on the board
/STEM/FAN_C/FANFAN A/OUT2: R22.2, W22.3 (Out2); also elsewhere on the board
/STEM/FAN_C/FANFAN A/OUT3: R23.1, W23.2 (Out1); also elsewhere on the board
/STEM/FAN_C/FANFAN A/OUT4: R23.2, W23.3 (Out2); also elsewhere on the board
/STEM/FAN_C/FANFAN A/OUT5: R24.1, W24.2 (Out1); also elsewhere on the board
/STEM/FAN_C/FANFAN A/OUT6: R24.2, W24.3 (Out2); also elsewhere on the board
/STEM/FAN_C/IN: W19.1 (In); also elsewhere on the board
/STEM/FAN_D/FANFAN A/OUT1: R28.1, W28.2 (Out1); also elsewhere on the board
/STEM/FAN_D/FANFAN A/OUT2: R28.2, W28.3 (Out2); also elsewhere on the board
/STEM/FAN_D/FANFAN A/OUT3: R29.1, W29.2 (Out1); also elsewhere on the board
/STEM/FAN_D/FANFAN A/OUT4: R29.2, W29.3 (Out2); also elsewhere on the board
/STEM/FAN_D/FANFAN A/OUT5: R30.1, W30.2 (Out1); also elsewhere on the board
/STEM/FAN_D/FANFAN A/OUT6: R30.2, W30.3 (Out2); also elsewhere on the board
/STEM/FAN_D/IN: W25.1 (In); also elsewhere on the board
/STEM/FAN_E/FANFAN A/OUT1: R34.1, W34.2 (Out1); also elsewhere on the board
/STEM/FAN_E/FANFAN A/OUT2: R34.2, W34.3 (Out2); also elsewhere on the board
/STEM/FAN_E/FANFAN A/OUT3: R35.1, W35.2 (Out1); also elsewhere on the board
/STEM/FAN_E/FANFAN A/OUT4: R35.2, W35.3 (Out2); also elsewhere on the board
/STEM/FAN_E/FANFAN A/OUT5: R36.1, W36.2 (Out1); also elsewhere on the board
/STEM/FAN_E/FANFAN A/OUT6: R36.2, W36.3 (Out2); also elsewhere on the board
/STEM/FAN_E/IN: W31.1 (In); also elsewhere on the board
/STEM/FAN_F/FANFAN A/OUT1: R40.1, W40.2 (Out1); also elsewhere on the board
/STEM/FAN_F/FANFAN A/OUT2: R40.2, W40.3 (Out2); also elsewhere on the board
/STEM/FAN_F/FANFAN A/OUT3: R41.1, W41.2 (Out1); also elsewhere on the board
/STEM/FAN_F/FANFAN A/OUT4: R41.2, W41.3 (Out2); also elsewhere on the board
/STEM/FAN_F/FANFAN A/OUT5: R42.1, W42.2 (Out1); also elsewhere on the board
/STEM/FAN_F/FANFAN A/OUT6: R42.2, W42.3 (Out2); also elsewhere on the board
/STEM/FAN_F/IN: W37.1 (In); also elsewhere on the board
GND: RL3.2, RL4.2, RL5.2, RL6.2, RL7.2; also elsewhere on the board
unnamed: R13.1, W13.2 (Out1), W14.1 (In)
unnamed: R13.2, W13.3 (Out2), W15.1 (In)
unnamed: R14.1, W14.2 (Out1), W16.1 (In)
unnamed: R14.2, W14.3 (Out2), W17.1 (In)
unnamed: R15.1, W15.2 (Out1), W18.1 (In)
unnamed: R15.2, RL3.1, W15.3 (Out2)
unnamed: R19.1, W19.2 (Out1), W20.1 (In)
unnamed: R19.2, W19.3 (Out2), W21.1 (In)
unnamed: R20.1, W20.2 (Out1), W22.1 (In)
unnamed: R20.2, W20.3 (Out2), W23.1 (In)
unnamed: R21.1, W21.2 (Out1), W24.1 (In)
unnamed: R21.2, RL4.1, W21.3 (Out2)
unnamed: R25.1, W25.2 (Out1), W26.1 (In)
unnamed: R25.2, W25.3 (Out2), W27.1 (In)
unnamed: R26.1, W26.2 (Out1), W28.1 (In)
unnamed: R26.2, W26.3 (Out2), W29.1 (In)
unnamed: R27.1, W27.2 (Out1), W30.1 (In)
unnamed: R27.2, RL5.1, W27.3 (Out2)
unnamed: R31.1, W31.2 (Out1), W32.1 (In)
unnamed: R31.2, W31.3 (Out2), W33.1 (In)
unnamed: R32.1, W32.2 (Out1), W34.1 (In)
unnamed: R32.2, W32.3 (Out2), W35.1 (In)
unnamed: R33.1, W33.2 (Out1), W36.1 (In)
unnamed: R33.2, RL6.1, W33.3 (Out2)
unnamed: R37.1, W37.2 (Out1), W38.1 (In)
unnamed: R37.2, W37.3 (Out2), W39.1 (In)
unnamed: R38.1, W38.2 (Out1), W40.1 (In)
unnamed: R38.2, W38.3 (Out2), W41.1 (In)
unnamed: R39.1, W39.2 (Out1), W42.1 (In)
unnamed: R39.2, RL7.1, W39.3 (Out2)

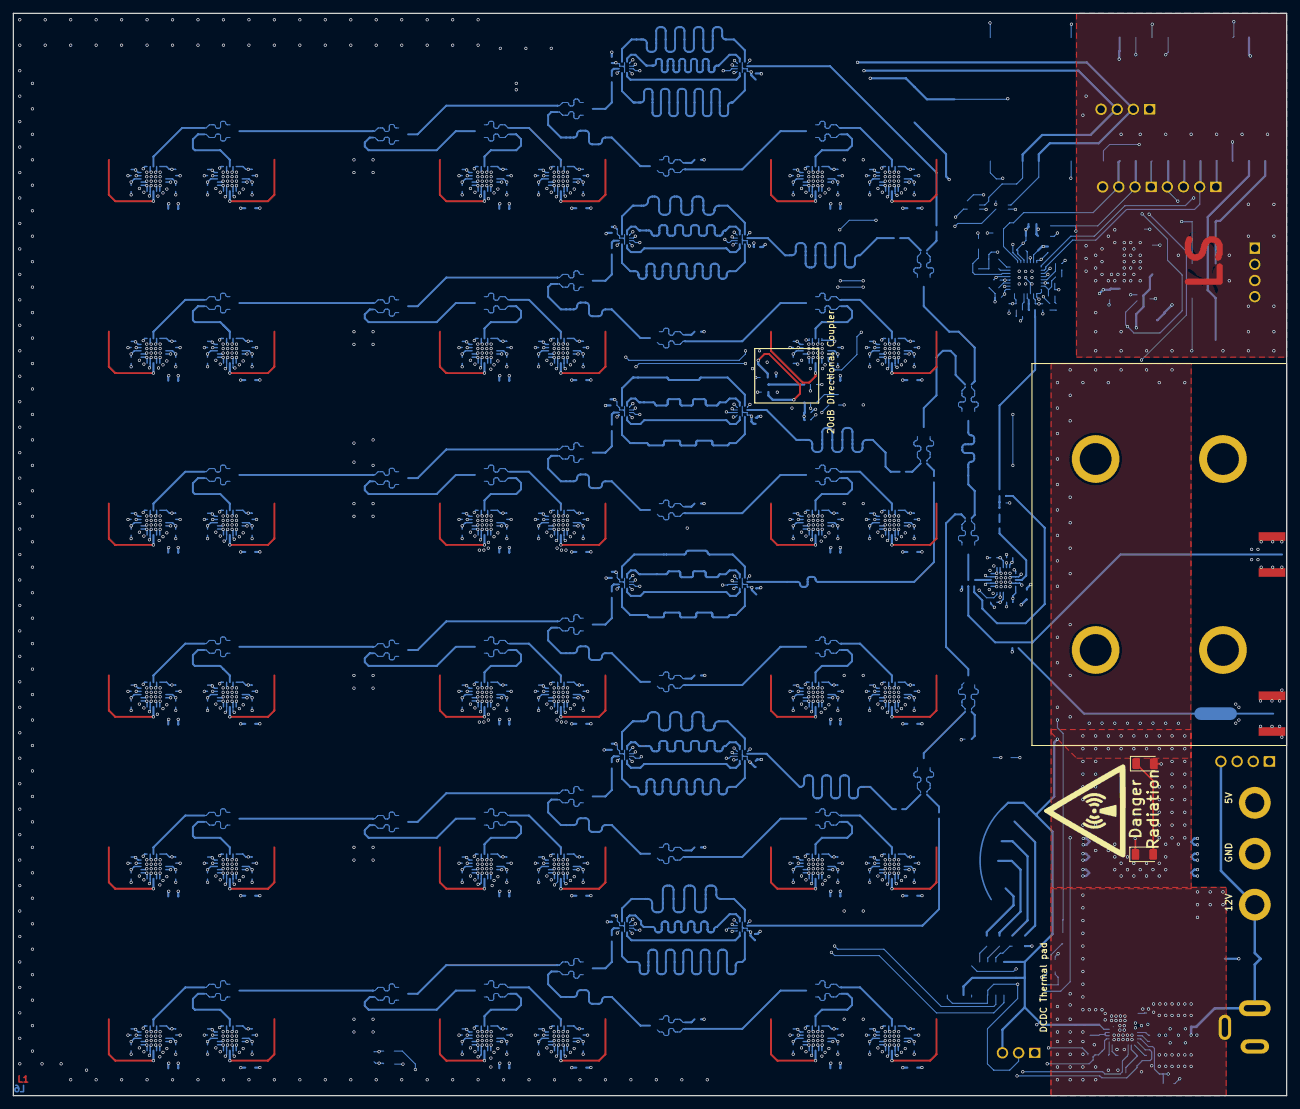
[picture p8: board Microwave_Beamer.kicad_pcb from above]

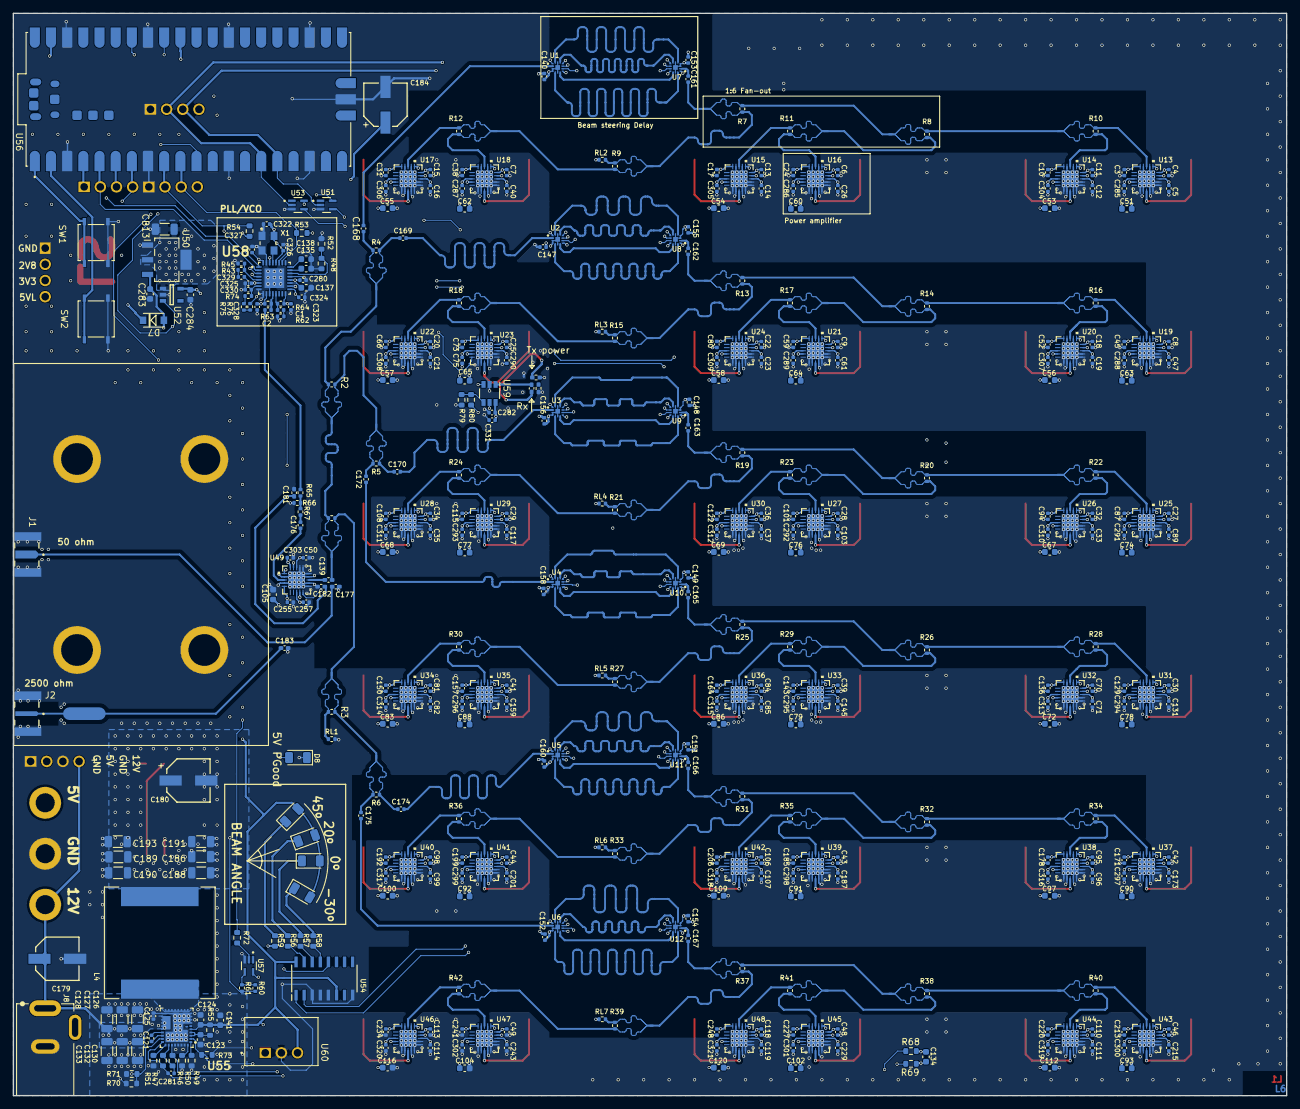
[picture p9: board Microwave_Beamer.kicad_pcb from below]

Board: 6 copper layers, 200.0 x 170.0 mm, 473 parts (464 on the bottom side), 198 nets.

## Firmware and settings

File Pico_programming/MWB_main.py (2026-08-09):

import machine
from machine import Pin, ADC
import utime

class MAX2870:
    def __init__(self, spi, pin_le, pin_ce, pin_rfen):
        """
        Microwave Beam's MAX2870 Synthesizer/VCO Controller
        Initializes with default values for 5.8GHz, 100MHz fREF, -4dBm Output A.
        """
        self.spi = spi
        self.le = pin_le
        self.ce = pin_ce
        self.rfen = pin_rfen
        
        # Initialize pins
        self.le.init(Pin.OUT, value=1) # LE idles high
        self.ce.init(Pin.OUT, value=1) # CE high enables the chip
        self.rfen.init(Pin.OUT, value=1) # RFEN high enables hardware RF output
        
        # MAX2870 Register Array (Defaults for 5.8GHz, Int-N, fREF=100MHz)
        # Register values are calculated based on the MAX2870 datasheet specifications.
        self.registers = [
            0x803A0000, # Reg 0: INT=1, N=58 (0x3A), FRAC=0, ADDR=000
            0x8000FFF9, # Reg 1: CPOC=1, CPL=0, Phase=1, Mod=4095, ADDR=001
            0x80005FA2, # Reg 2: LDS=1, SDN=0, R=1, CP=1111(5.12mA), LDF=1(Int-N), PDP=1, ADDR=010
            0x0000000B, # Reg 3: VAS_SHDN=0 (Auto VCO), ADDR=011
            0x638FF024, # Reg 4: FB=1, DIVA=000 (Div 1), RFA_EN=1, APWR=00 (-4dBm), ADDR=100
            0x01400005  # Reg 5: F01=1 (Auto Int), LD=01 (Digital Lock Detect), ADDR=101
        ]
        
        # Boot sequence: program registers twice with a pause to initialize VAS
        self.power_on_sequence()

    def send_to_device(self, val):
        """
        Handles the SPI protocol to write a 32-bit parameter to the registers.
        Data is latched into the shift register on the rising edge of CLK.
        At the rising edge of LE, data is latched into the addressed register.
        """
        # Convert the 32-bit integer to a 4-byte array (MSB first)
        data = val.to_bytes(4, 'big')
        
        # Pull Latch Enable (LE) low to start shifting
        self.le.value(0)
        
        # Send data over SPI
        self.spi.write(data)
        
        # Pulse Latch Enable (LE) high to latch the data into the register
        self.le.value(1)

    def power_on_sequence(self):
        """
        Upon power-up, the registers should be programmed twice with at least a 
        20ms pause between writes to ensure the device is enabled and the VCO 
        selection process starts.
        """
        print("Microwave Beam: Initiating power-on sequence...")
        self.ce.value(1) # Ensure chip is enabled
        
        for _ in range(2):
            # Programming order must be 0x05, 0x04, 0x03, 0x02, 0x01, and 0x00
            for i in range(5, -1, -1):
                self.send_to_device(self.registers[i])
            utime.sleep_ms(20)
            
        print("Microwave Beam: PLL Locked and Loaded!")

    def set_output_a_power(self, power_level):
        """
        Updates the APWR bits in Register 4.
        power_level: 0 = -4dBm, 1 = -1dBm, 2 = +2dBm, 3 = +5dBm
        """
        if power_level < 0 or power_level > 3:
            raise ValueError("Power level must be between 0 and 3")
            
        # Clear current APWR bits (bits 4:3) and set new power level
        reg4 = self.registers[4]
        reg4 &= ~(0b11 << 3) 
        reg4 |= (power_level << 3)
        self.registers[4] = reg4
        
        # Send updated register 4 to the device
        self.send_to_device(self.registers[4])
        print(f"Microwave Beam: Output A power adjusted to setting {power_level}.")


# ==========================================
# Main Execution for Raspberry Pi Pico
# ==========================================
if __name__ == '__main__':
    # Pin definitions based on your request
    PIN_SCK  = 2
    PIN_MOSI = 3
    PIN_LE   = 5
    PIN_CE   = 6
    PIN_RFEN = 7
    
    # Configure hardware SPI on the Pico
    # The MAX2870 latches data on the rising edge of CLK, MSB first
    spi0 = machine.SPI(0, baudrate=10_000_000, polarity=0, phase=0,
                       sck=Pin(PIN_SCK), mosi=Pin(PIN_MOSI))

    # Initialize control pins
    le_pin = Pin(PIN_LE)
    ce_pin = Pin(PIN_CE)
    rfen_pin = Pin(PIN_RFEN)
    
    # Instantiate the VCO controller
    # The __init__ function automatically loads the 5.8GHz defaults!
    vco = MAX2870(spi=spi0, pin_le=le_pin, pin_ce=ce_pin, pin_rfen=rfen_pin)
    button_1 = Pin(0, Pin.IN, Pin.PULL_UP)
    button_2 = Pin(1, Pin.IN, Pin.PULL_UP)
    ADC_stage_1_power = ADC(Pin(26))
    ADC_stage_2_power = ADC(Pin(27))
    ADC_coupled_power = ADC(Pin(28))
    # Example: Change power level to +5dBm dynamically
    # vco.set_output_a_power(3)

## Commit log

2026-05-03 moving along
    [Microwave_Beamer.kicad_pcb, Microwave_Beamer.kicad_sch, Stage_A.kicad_sch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]
2026-05-04 6 layers now
    [FANFAN.kicad_sch, Microwave_Beamer.kicad_pcb, Microwave_Beamer.kicad_sch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]
2026-05-24 completed length matching
    [Microwave_Beamer.kicad_pcb, Microwave_Beamer.kicad_sch, POWER_AMP.kicad_sch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]
2026-07-10 created fab files, needs some cleanup
    [Microwave_Beamer.kicad_pcb, Microwave_Beamer.kicad_sch, POWER_AMP.kicad_sch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]
2026-07-22 created version with standard stackup
    [Microwave_Beamer.kicad_pcb, Microwave_Beamer.kicad_sch, power.kicad_sch]
2026-08-09 updated bom
    [Microwave_Beamer.kicad_sch, POWER_AMP.kicad_sch, POWER_AMP2.kicad_sch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]
2026-08-09 arranged folders
    [.kicad_sch, FANFAN.kicad_sch, Microwave_Beamer.kicad_pcb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]
